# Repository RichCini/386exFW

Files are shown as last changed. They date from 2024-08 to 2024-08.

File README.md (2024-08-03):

# 386ex Firmware Prototyping/Design Board
386EX-target firmware design board based on the design from Ed Nisley and his Firmware Furnace column
in Circuit Cellar. The article series spanned Issues 31 to 65 (roughly 1993 to 1995). The hardware
design -- a short ISA card built on a Jameco prototyping card -- provided an easy way to interface
to the ISA bus and had memory (EEPROM/ROM/NVRAM). a timer, watchdog, LED and switch inputs, and two
types of LCD displays. 

The first part of the series (Issues 31- 46) dealt with the hardware design, while later articles
discussed something Ed called the "Firmware Furnace Task Switcher", a functional protected-mode
software platform. The software discussion began in Issue 48 and ended with Issue 65. Issue 65
seems to point to future columns on the topic, but they never seemed to appear.

## Status
The schematics have been converted and the board plotted. It has not been built yet. Of the
design elements, the only feature I didn't redraw was the bitmapped graphics LCD panel, the
discission of which began in Issue 42. Options were the Optrex (Kyocera) DMF651 640x200 or the 
Matsushita EDM-LG64AA44D 640x400 panel.

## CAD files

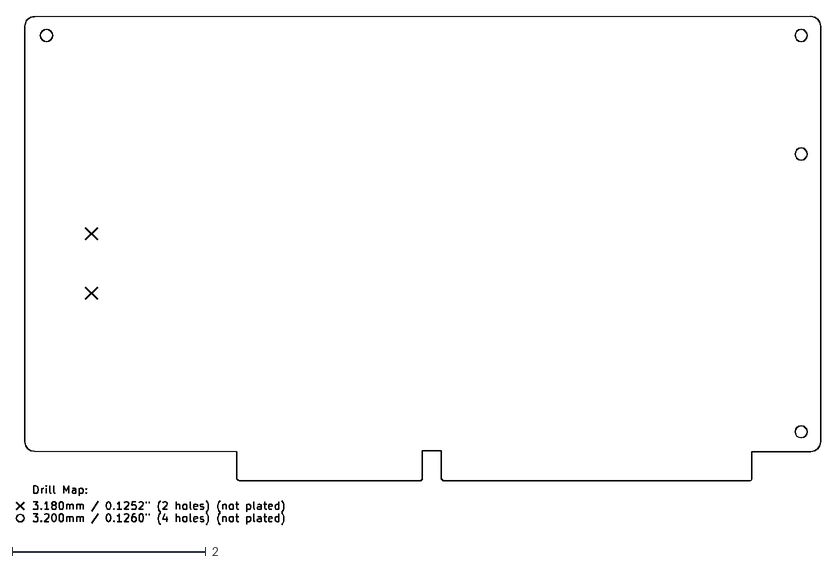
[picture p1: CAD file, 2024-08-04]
mfg/386sxEmbedded-NPTH-drl_map.dxf
8.30 x 5.24

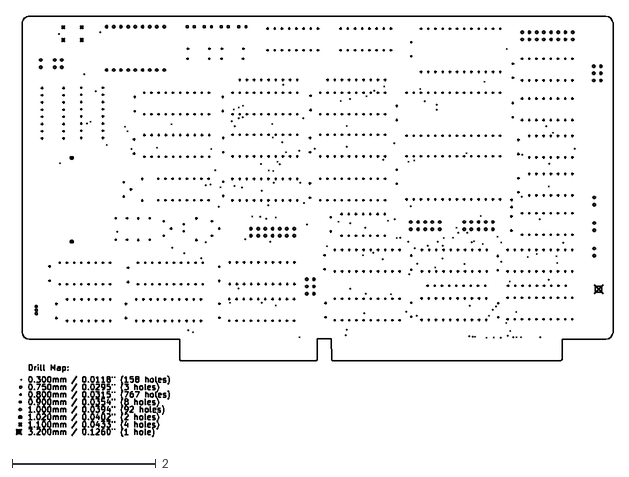
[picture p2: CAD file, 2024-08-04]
mfg/386sxEmbedded-PTH-drl_map.dxf
8.30 x 5.84

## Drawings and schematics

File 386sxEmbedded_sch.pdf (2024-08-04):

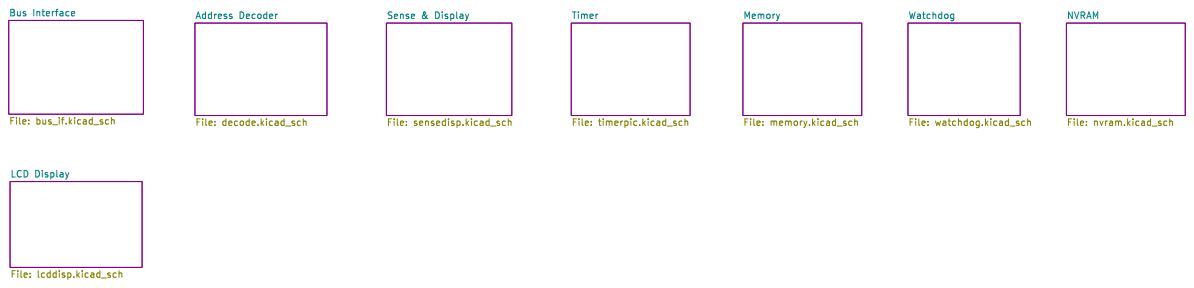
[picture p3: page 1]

Id: 1/9 Title: 386SX Embedded Expansion Card

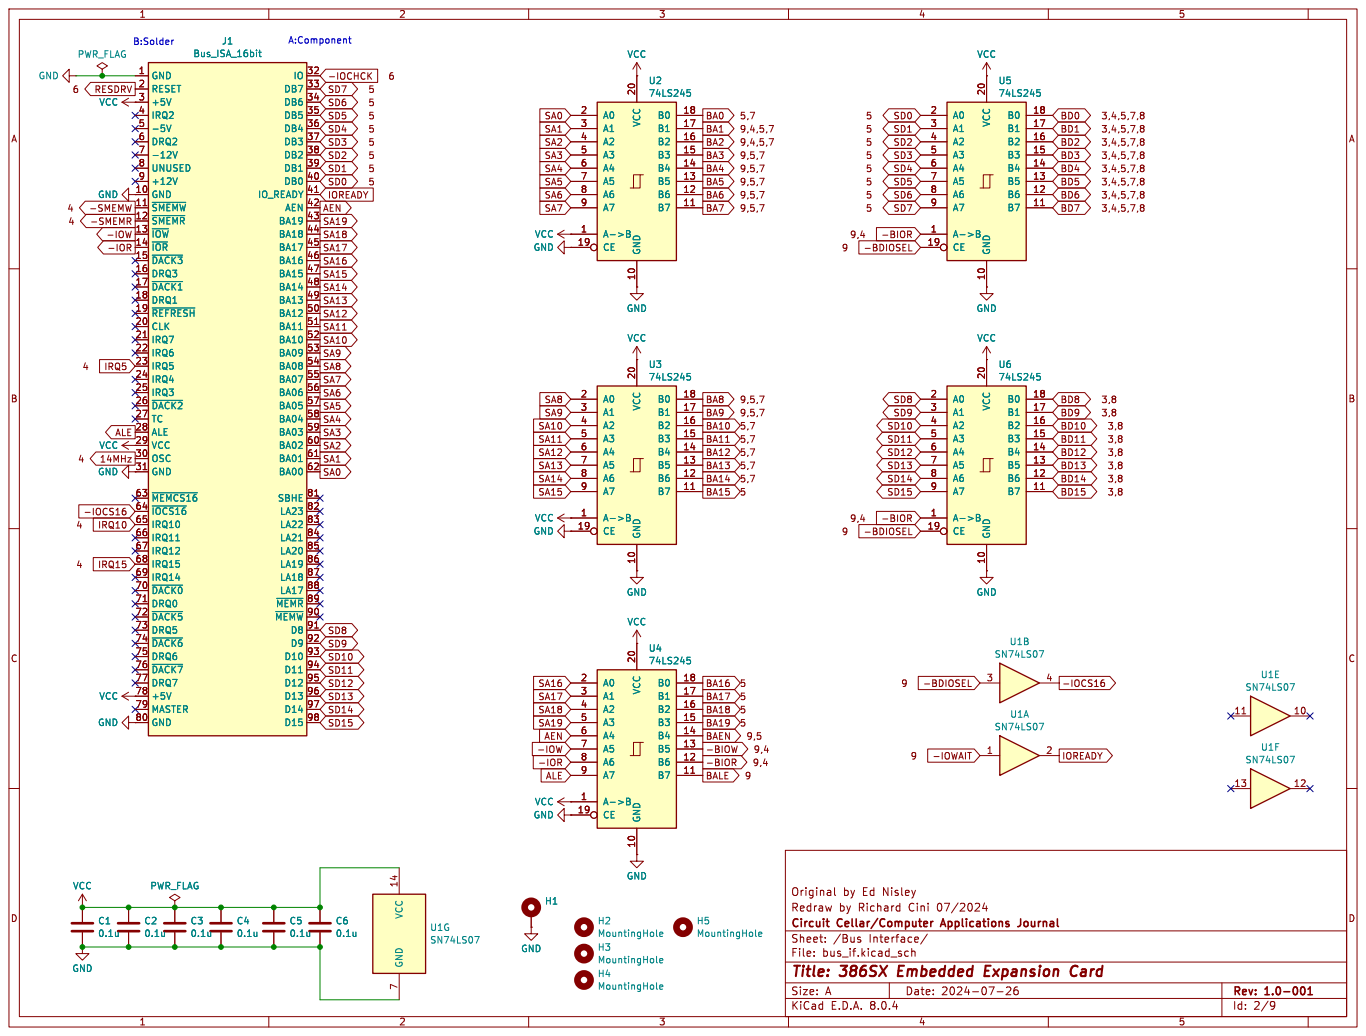
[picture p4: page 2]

Id: 2/9 Title: 386SX Embedded Expansion Card

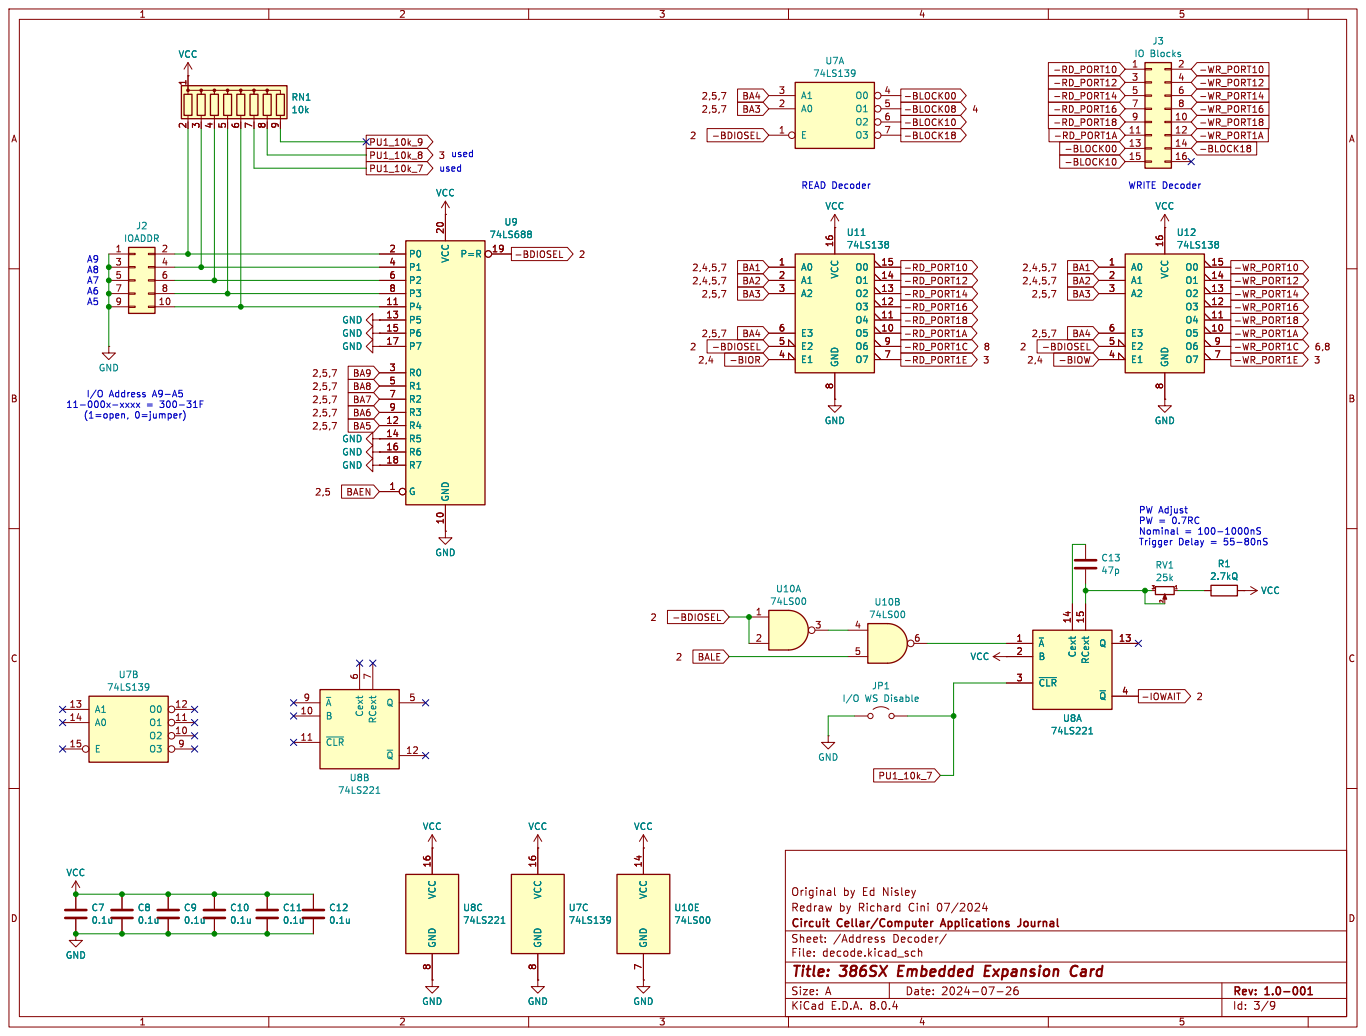
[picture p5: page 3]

8 O6 9 VCC GND GND GND GND GND GND GND

Id: 3/9 Title: 386SX Embedded Expansion Card

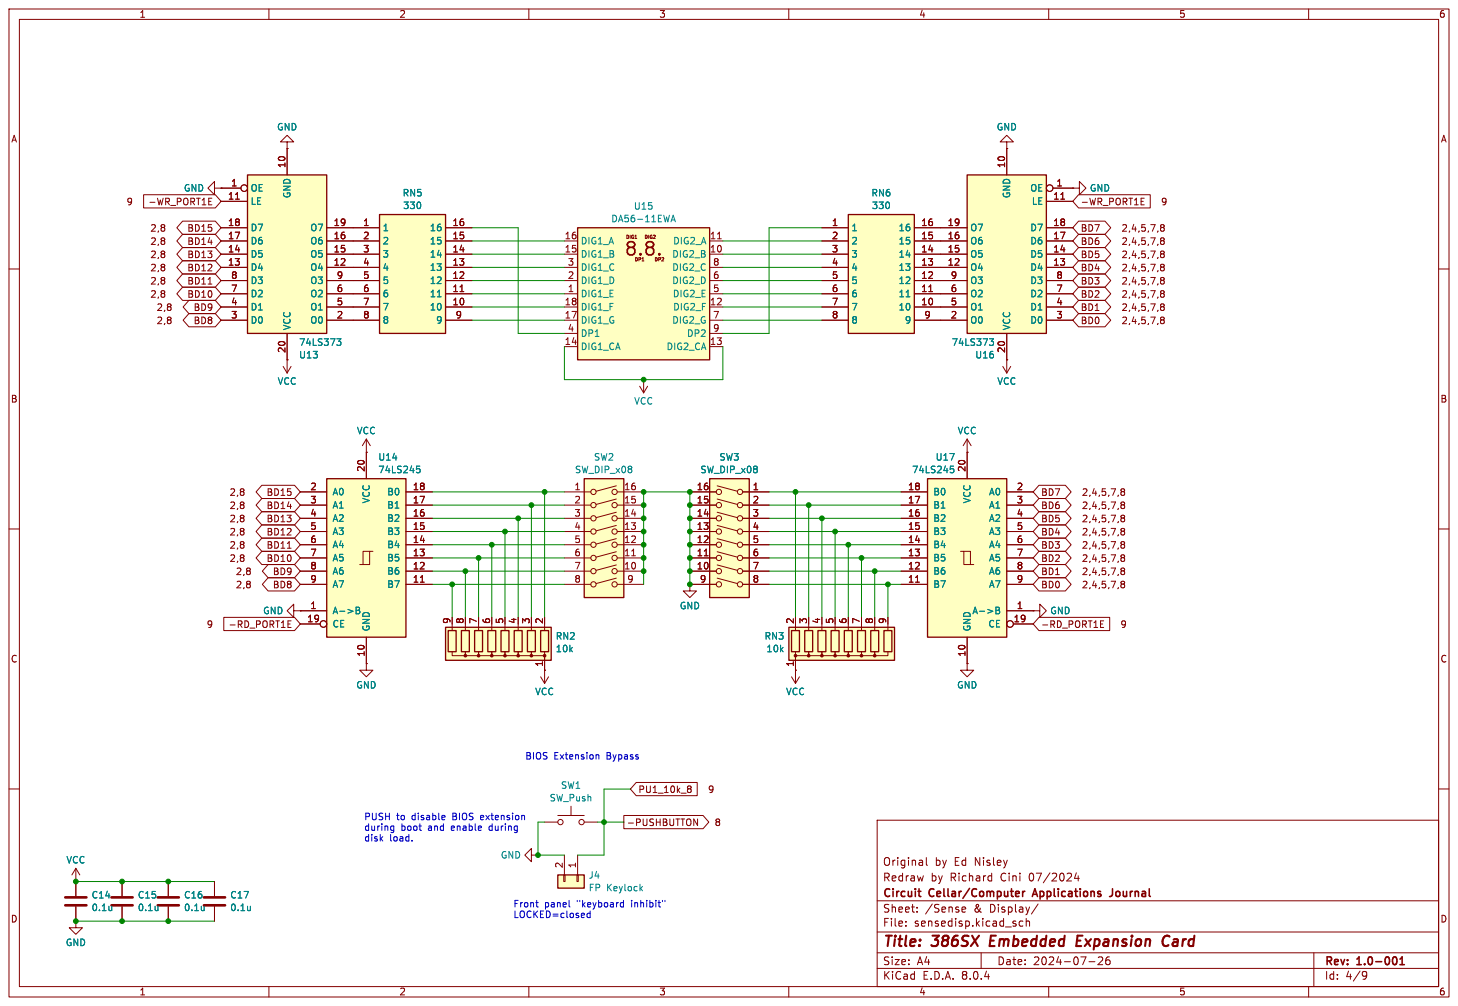
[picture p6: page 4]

during boot and enable during

Id: 4/9 Title: 386SX Embedded Expansion Card

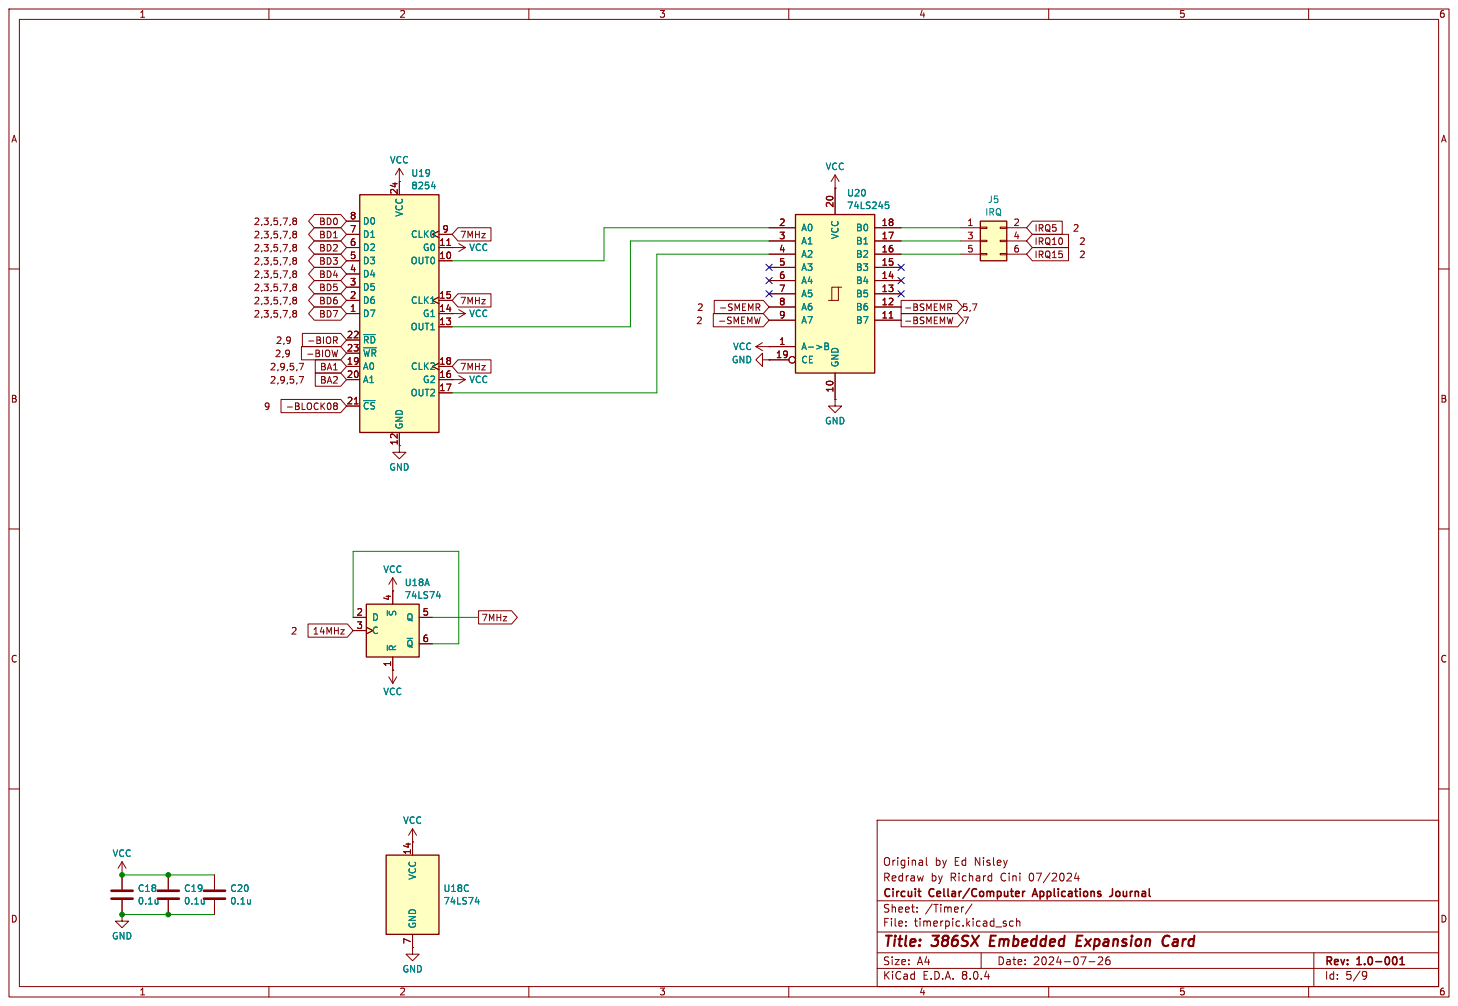
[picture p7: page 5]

Id: 5/9 Title: 386SX Embedded Expansion Card

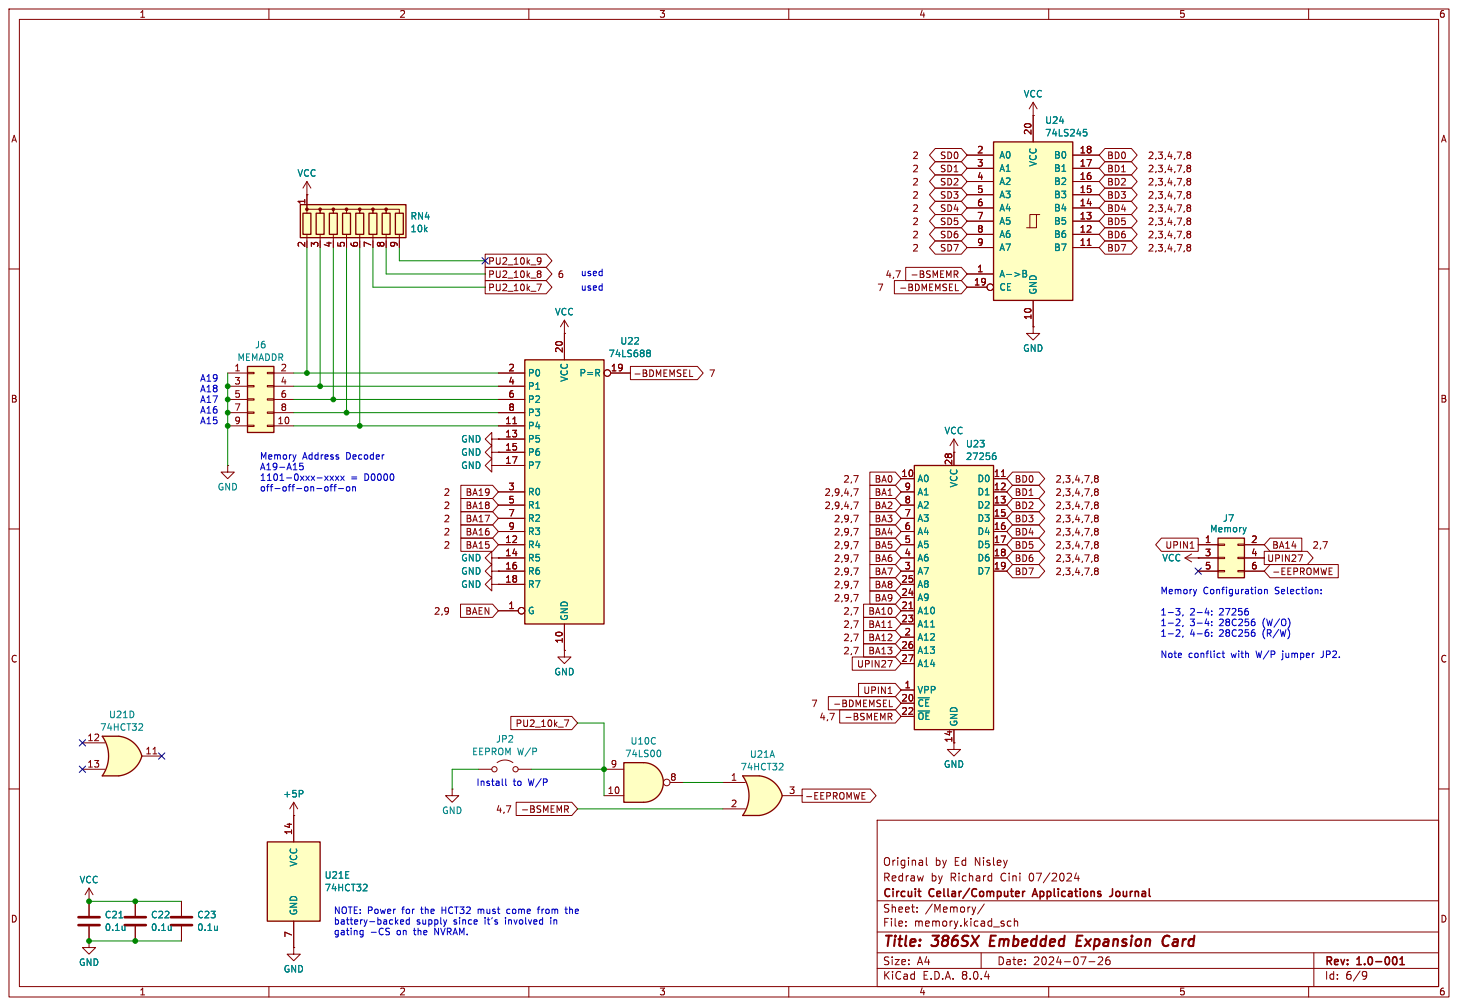
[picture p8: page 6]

9 VCC GND GND GND GND GND GND

off-off-on-off-on

gating -CS on the NVRAM.

Id: 6/9 Title: 386SX Embedded Expansion Card

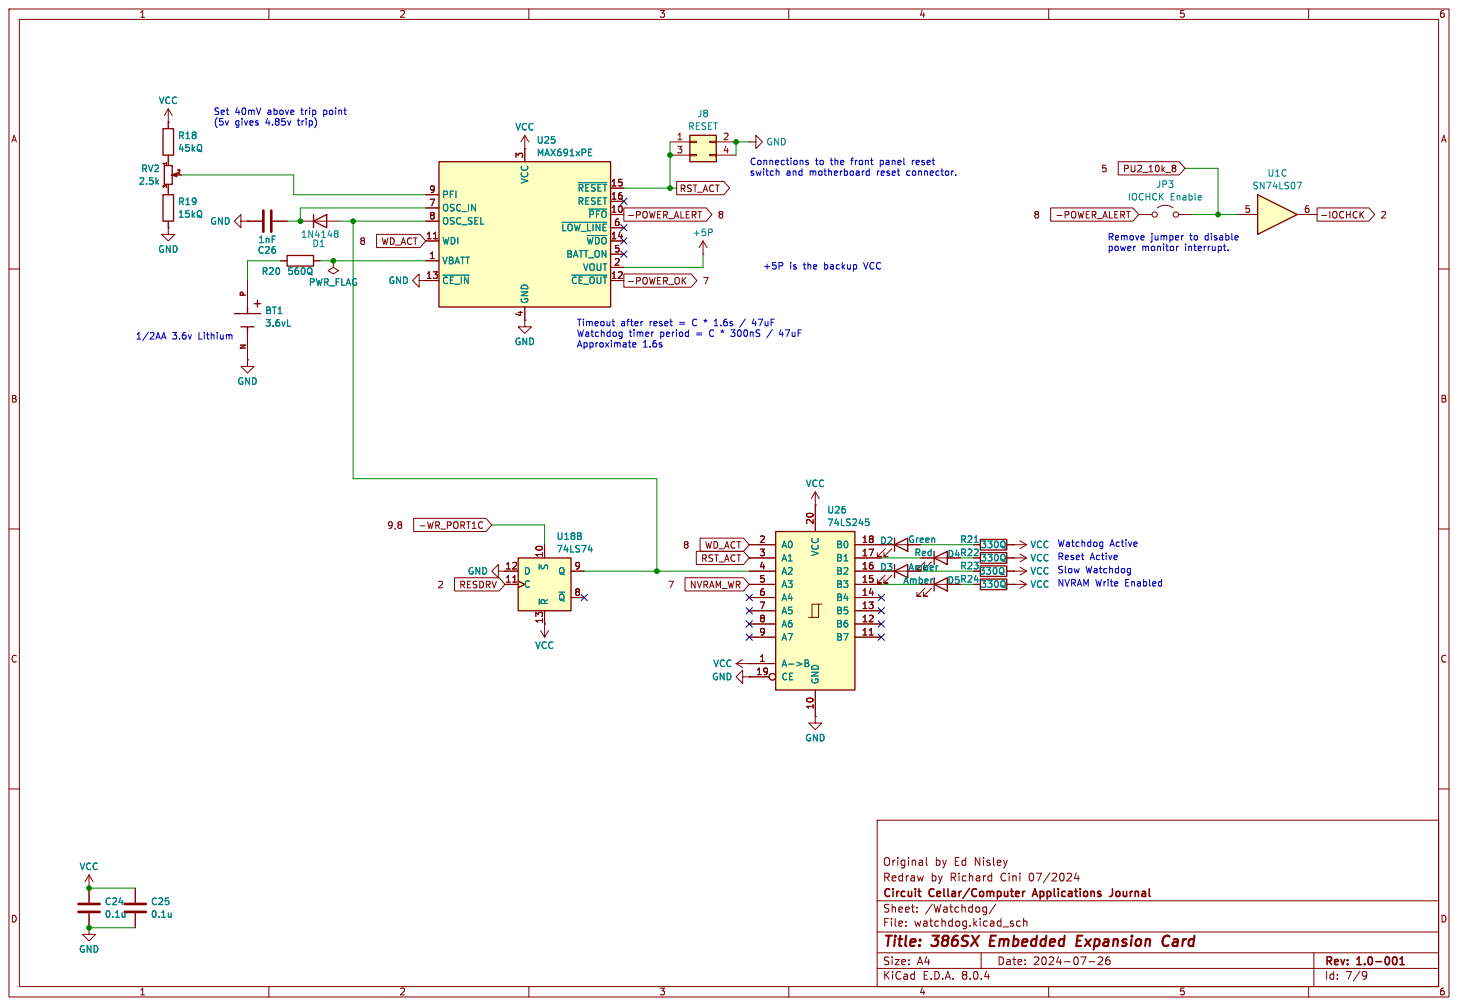
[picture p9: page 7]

Set 40mV above trip point

Id: 7/9 Title: 386SX Embedded Expansion Card

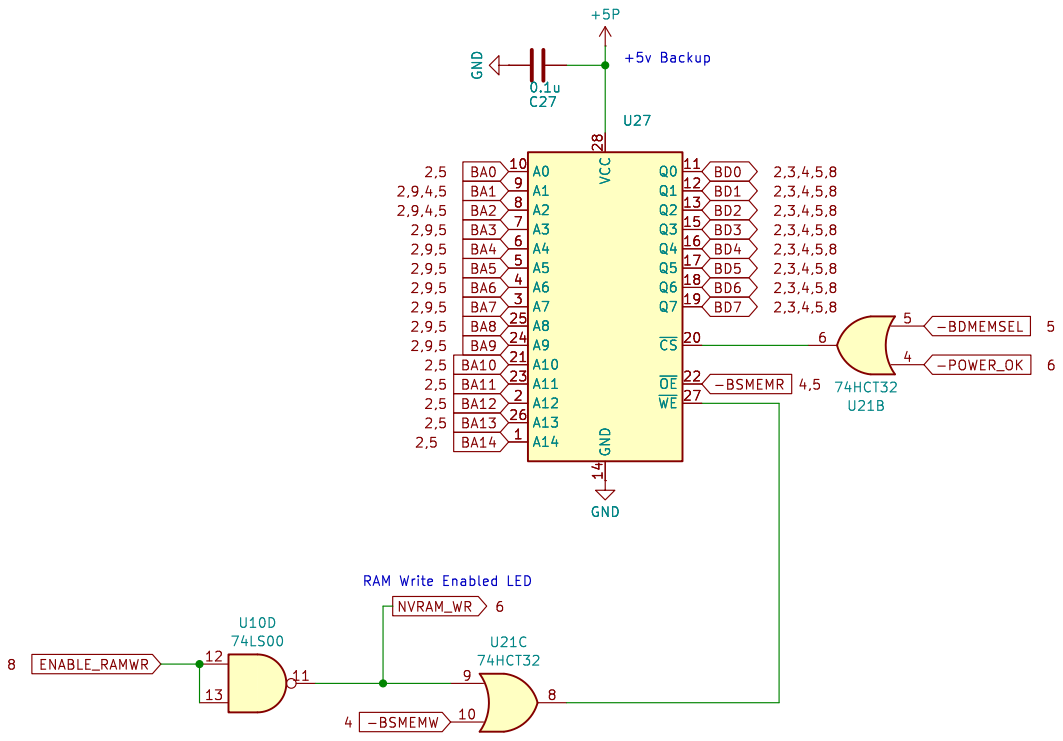
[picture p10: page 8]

Id: 8/9 Title: 386SX Embedded Expansion Card

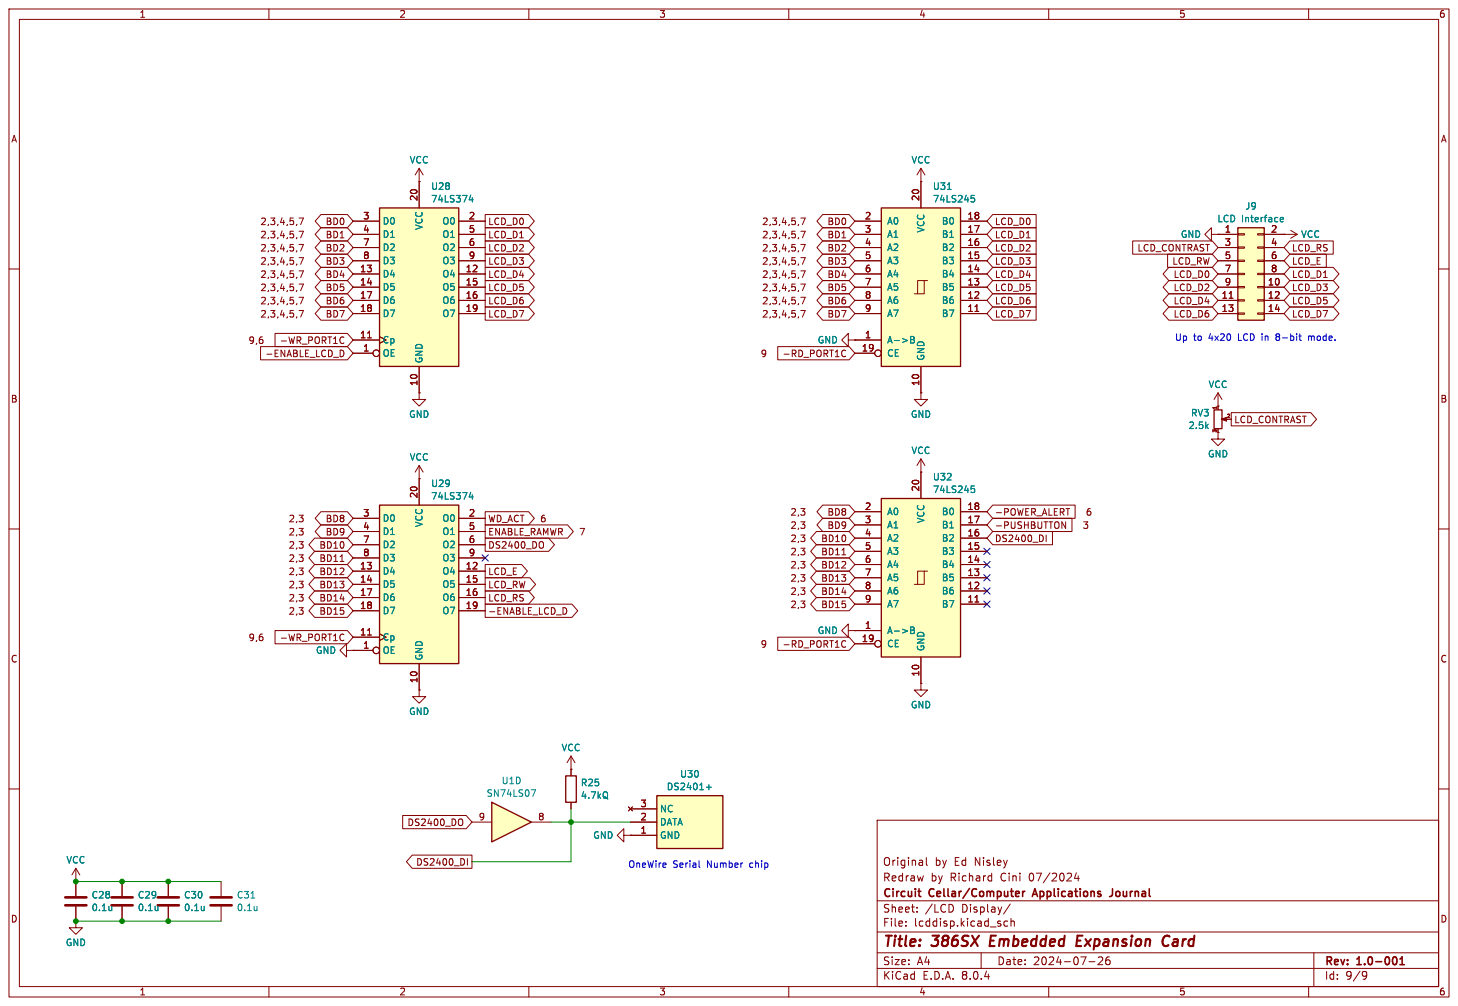
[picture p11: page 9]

Id: 9/9 Title: 386SX Embedded Expansion Card

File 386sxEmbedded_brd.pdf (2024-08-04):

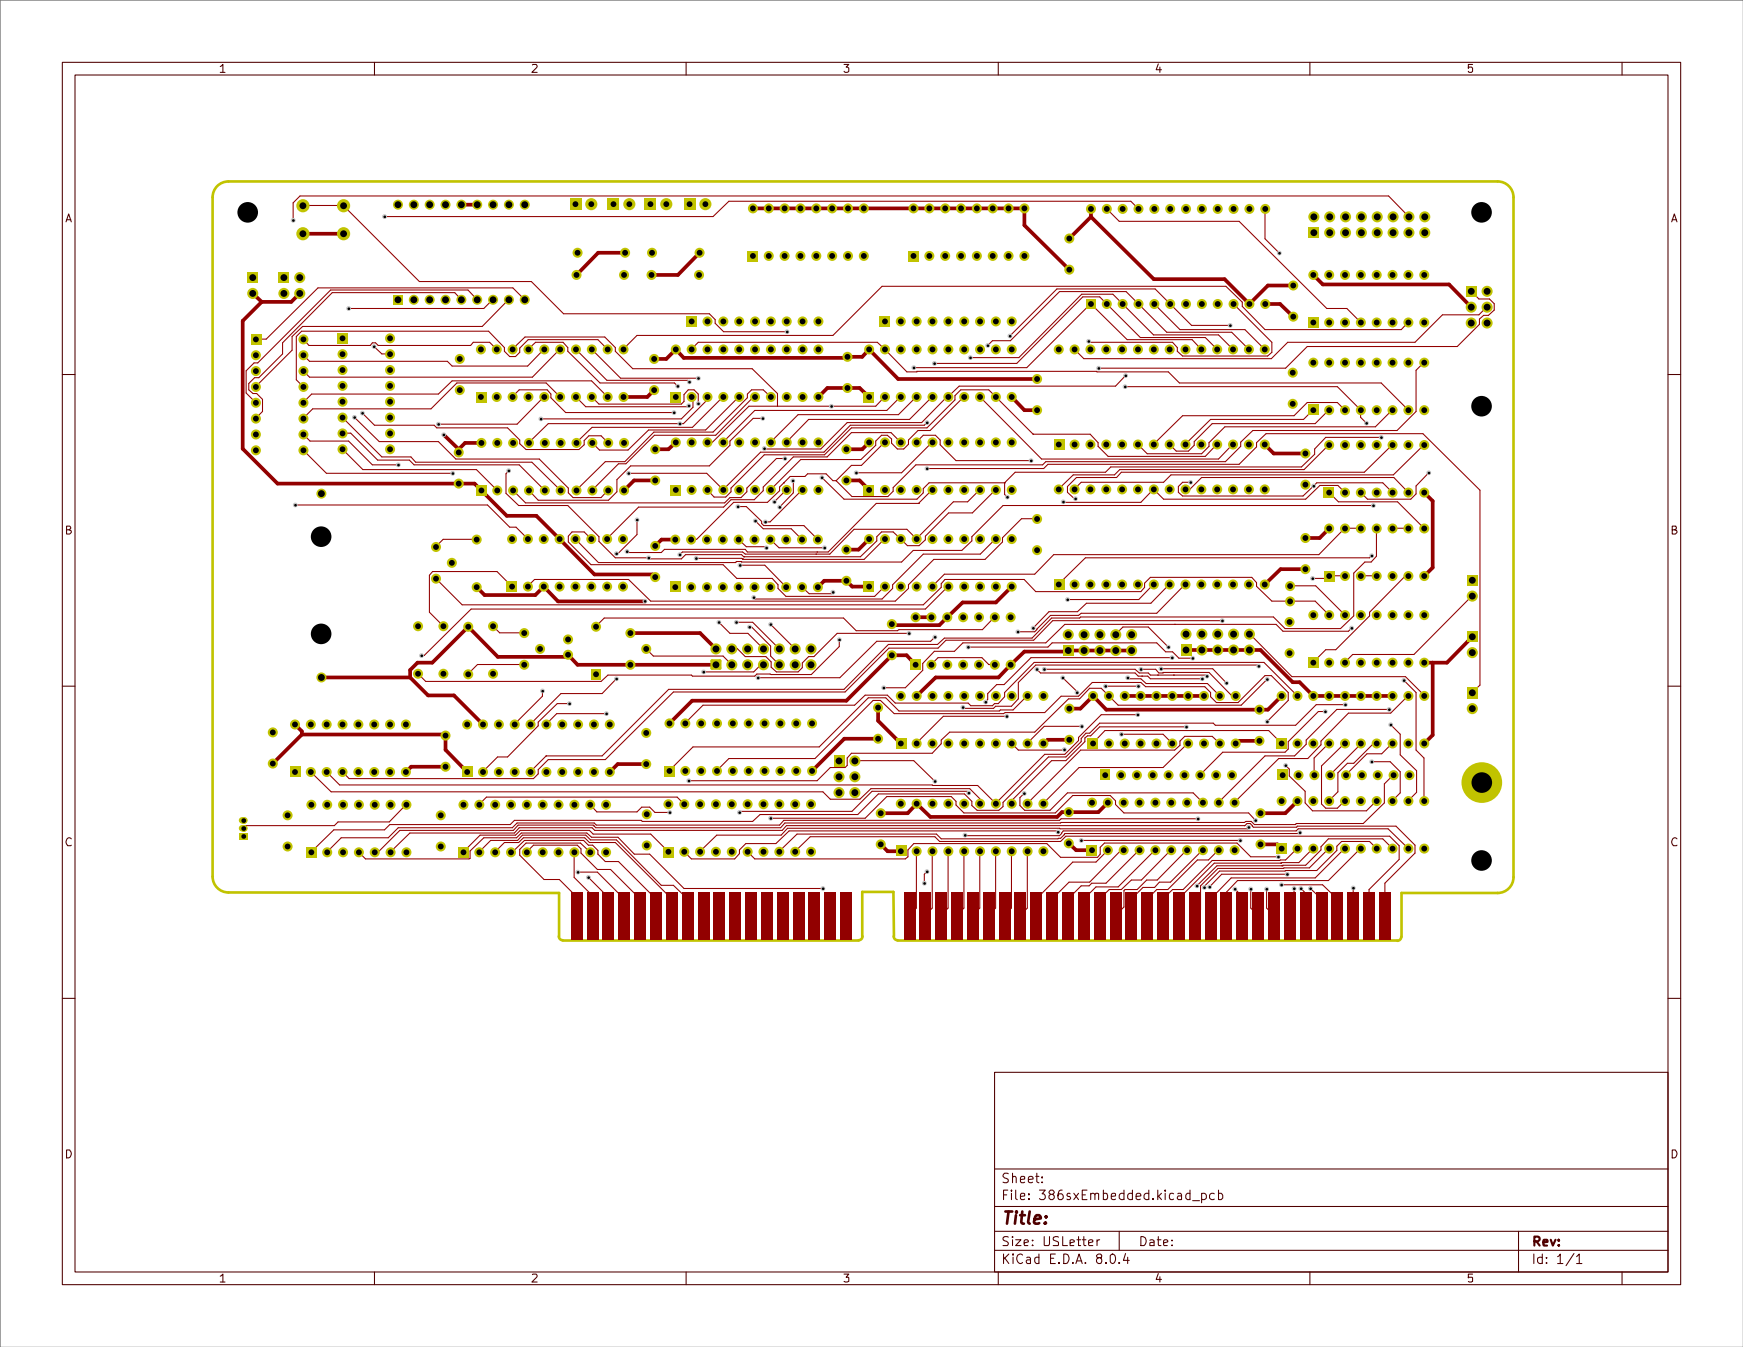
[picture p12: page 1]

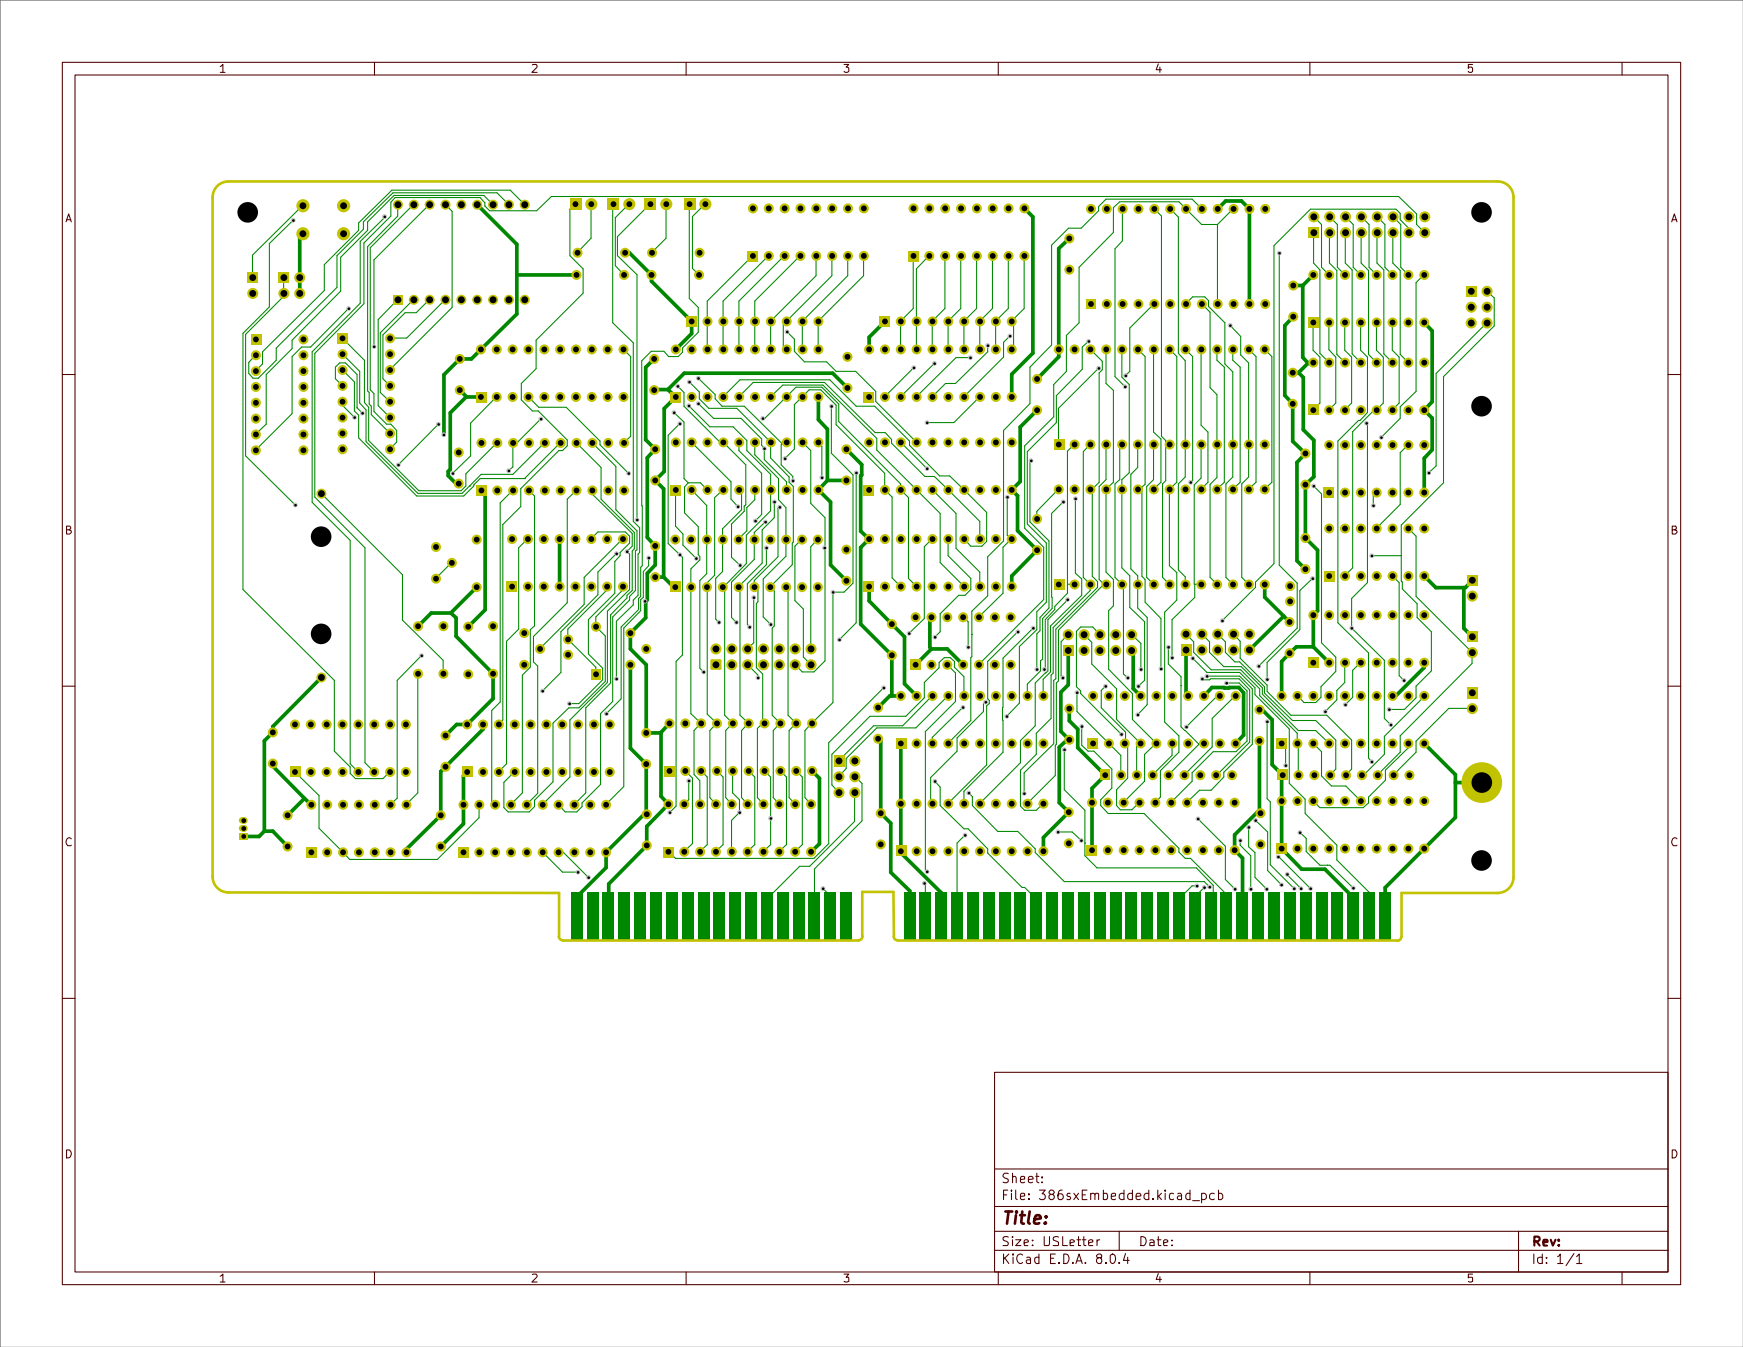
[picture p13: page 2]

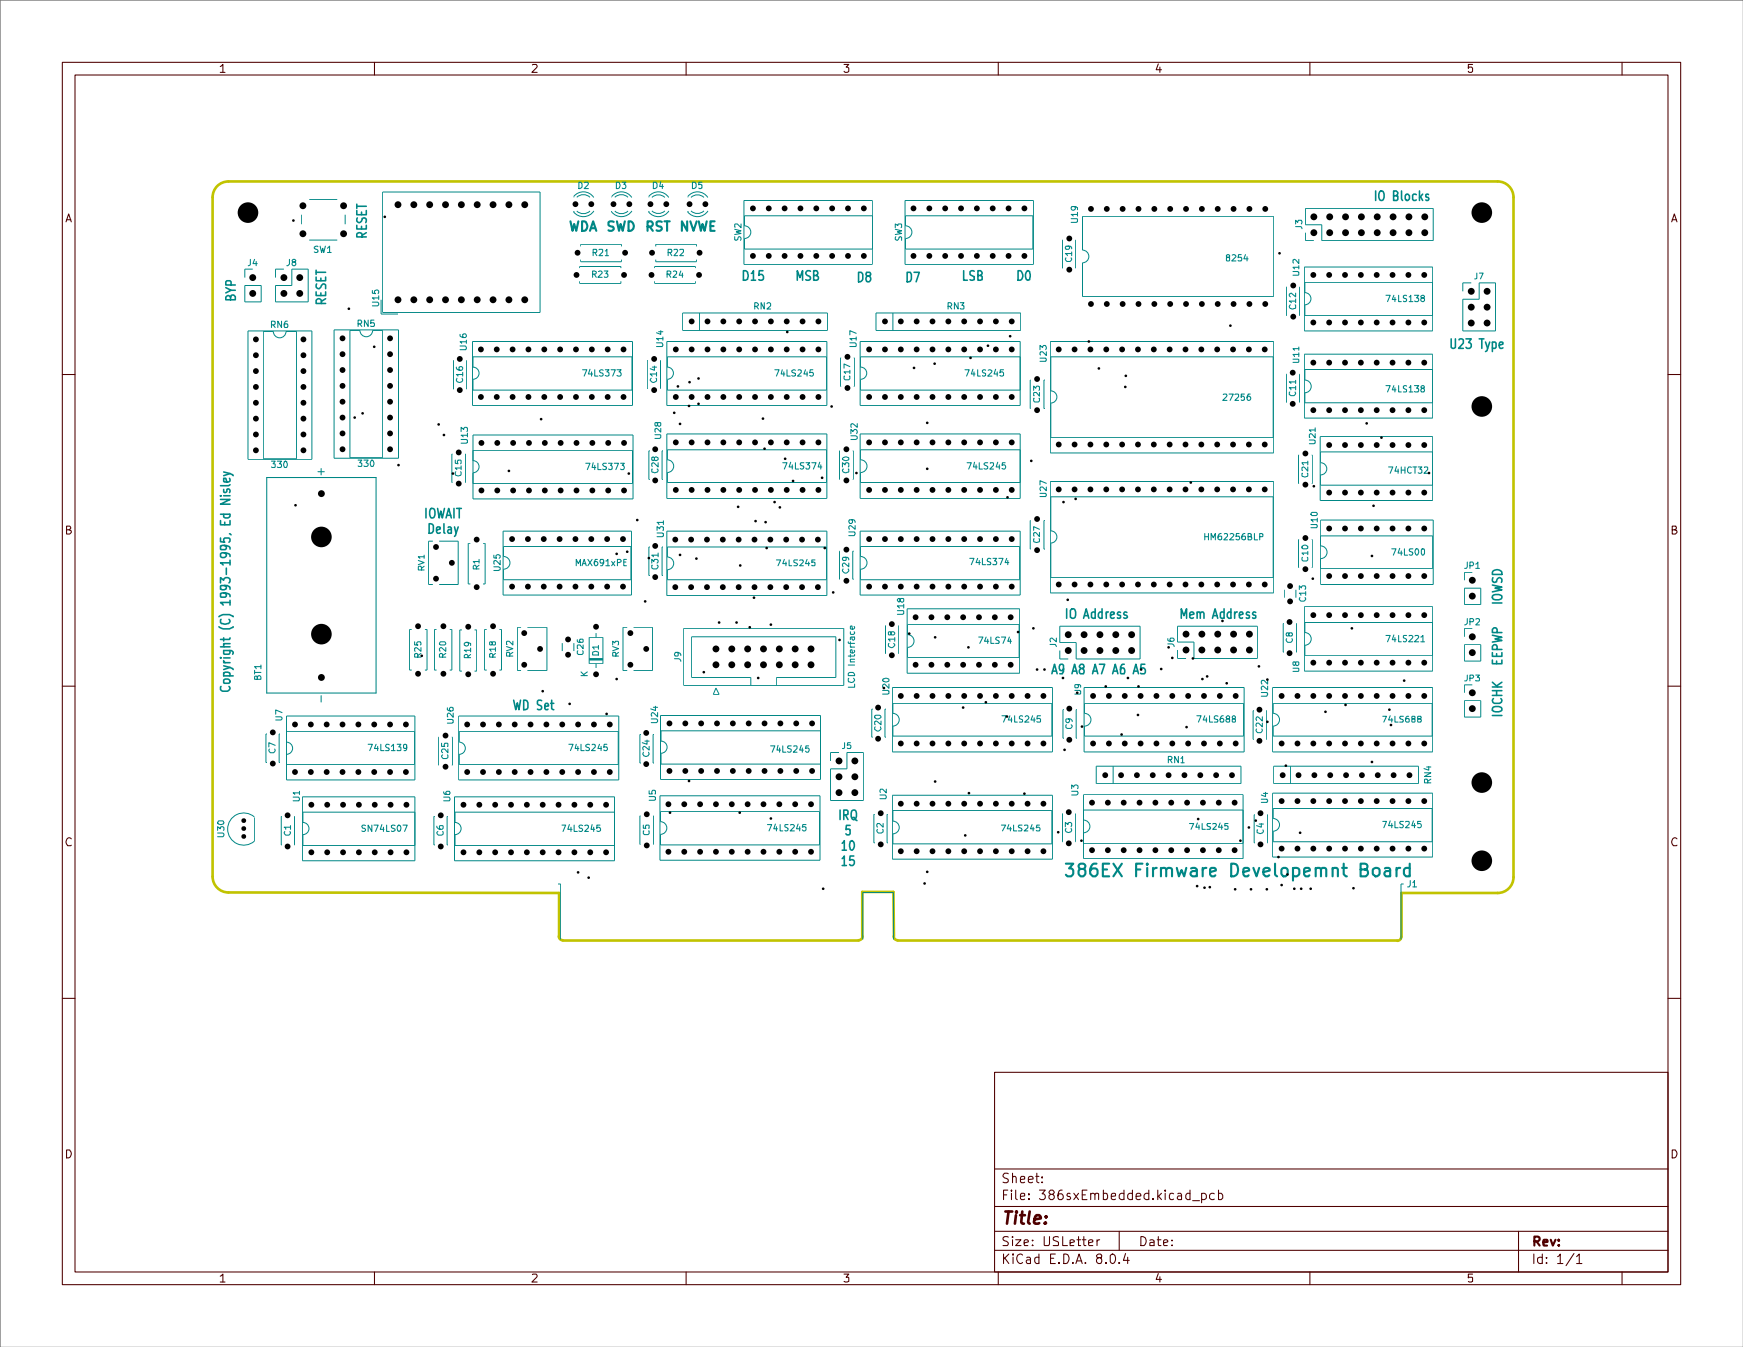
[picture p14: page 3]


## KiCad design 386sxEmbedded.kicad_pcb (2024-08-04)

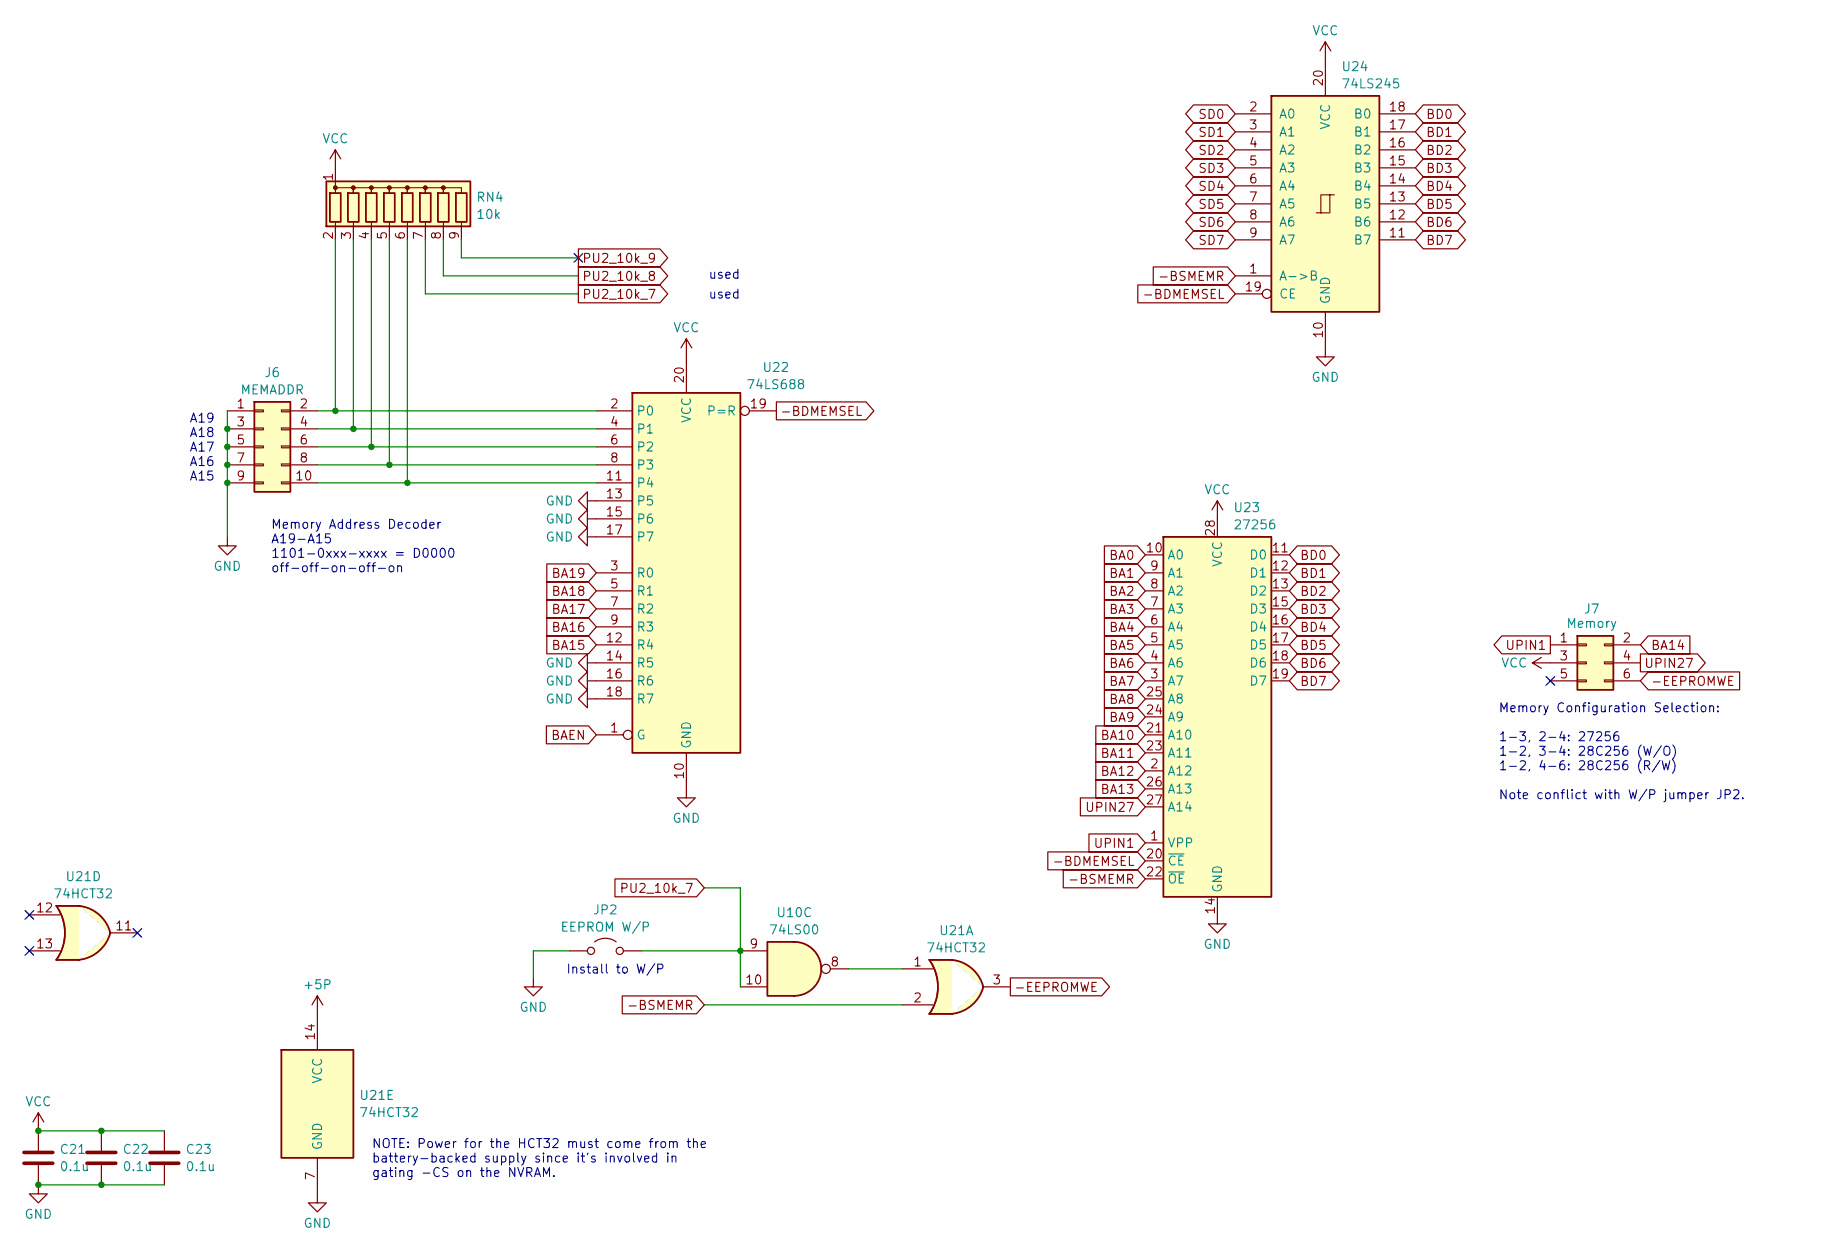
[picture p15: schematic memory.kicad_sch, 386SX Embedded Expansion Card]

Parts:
C21, C22, C23: 0.1u; C_Disc_D4.3mm_W1.9mm_P5.00mm
J6: MEMADDR; PinHeader_2x05_P2.54mm_Vertical
J7: Memory; PinHeader_2x03_P2.54mm_Vertical
JP2: EEPROM W/P; PinHeader_1x02_P2.54mm_Vertical
RN4: 10k; R_Array_SIP9
U10: 74LS00; DIP-14_W7.62mm_Socket
U21: 74HCT32; DIP-14_W7.62mm_Socket
U22: 74LS688; DIP-20_W7.62mm_Socket
U23: 27256; DIP-28_W15.24mm_Socket
U24: 74LS245; DIP-20_W7.62mm_Socket

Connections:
+5P: U21.14 (VCC); also elsewhere on the board
-BDMEMSEL: U22.19 (P=R), U23.20 (~CE), U24.19 (CE); also elsewhere on the board
-BSMEMR: U21.2, U23.22 (~OE), U24.1 (A->B); also elsewhere on the board
-EEPROMWE: J7.6, U21.3
BA0: U23.10 (A0); also elsewhere on the board
BA1: U23.9 (A1); also elsewhere on the board
BA2: U23.8 (A2); also elsewhere on the board
BA3: U23.7 (A3); also elsewhere on the board
BA4: U23.6 (A4); also elsewhere on the board
BA5: U23.5 (A5); also elsewhere on the board
BA6: U23.4 (A6); also elsewhere on the board
BA7: U23.3 (A7); also elsewhere on the board
BA8: U23.25 (A8); also elsewhere on the board
BA9: U23.24 (A9); also elsewhere on the board
BA10: U23.21 (A10); also elsewhere on the board
BA11: U23.23 (A11); also elsewhere on the board
BA12: U23.2 (A12); also elsewhere on the board
BA13: U23.26 (A13); also elsewhere on the board
BA14: J7.2; also elsewhere on the board
BA15: U22.12 (R4); also elsewhere on the board
BA16: U22.9 (R3); also elsewhere on the board
BA17: U22.7 (R2); also elsewhere on the board
BA18: U22.5 (R1); also elsewhere on the board
BA19: U22.3 (R0); also elsewhere on the board
BAEN: U22.1 (G); also elsewhere on the board
BD0: U23.11 (D0), U24.18 (B0); also elsewhere on the board
BD1: U23.12 (D1), U24.17 (B1); also elsewhere on the board
BD2: U23.13 (D2), U24.16 (B2); also elsewhere on the board
BD3: U23.15 (D3), U24.15 (B3); also elsewhere on the board
BD4: U23.16 (D4), U24.14 (B4); also elsewhere on the board
BD5: U23.17 (D5), U24.13 (B5); also elsewhere on the board
BD6: U23.18 (D6), U24.12 (B6); also elsewhere on the board
BD7: U23.19 (D7), U24.11 (B7); also elsewhere on the board
GND: C21.2, C22.2, C23.2, J6.1, J6.3, J6.5, J6.7, J6.9, JP2.1 (A), U21.7 (GND), U22.10 (GND), U22.13 (P5), U22.14 (R5), U22.15 (P6), U22.16 (R6), U22.17 (P7), U22.18 (R7), U23.14 (GND), U24.10 (GND); also elsewhere on the board
unnamed: J6.2, RN4.2 (R1), U22.2 (P0)
unnamed: J6.4, RN4.3 (R2), U22.4 (P1)
unnamed: J6.6, RN4.4 (R3), U22.6 (P2)
unnamed: J6.8, RN4.5 (R4), U22.8 (P3)
unnamed: J6.10, RN4.6 (R5), U22.11 (P4)
unnamed: U10.8, U21.1
PU2_10k_7: JP2.2 (B), RN4.7 (R6), U10.9, U10.10
PU2_10k_8: RN4.8 (R7); also elsewhere on the board
PU2_10k_9: RN4.9 (R8)
SD0: U24.2 (A0); also elsewhere on the board
SD1: U24.3 (A1); also elsewhere on the board
SD2: U24.4 (A2); also elsewhere on the board
SD3: U24.5 (A3); also elsewhere on the board
SD4: U24.6 (A4); also elsewhere on the board
SD5: U24.7 (A5); also elsewhere on the board
SD6: U24.8 (A6); also elsewhere on the board
SD7: U24.9 (A7); also elsewhere on the board
UPIN1: J7.1, U23.1 (VPP)
UPIN27: J7.4, U23.27 (A14)
VCC: C21.1, C22.1, C23.1, J7.3, RN4.1 (common), U22.20 (VCC), U23.28 (VCC), U24.20 (VCC); also elsewhere on the board

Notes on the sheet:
used
NOTE: Power for the HCT32 must come from the battery-backed supply since it's involved in gating -CS on the NVRAM.
Memory Address Decoder A19-A15 1101-0xxx-xxxx = D0000 off-off-on-off-on
Memory Configuration Selection: 1-3, 2-4: 27256 1-2, 3-4: 28C256 (W/O) 1-2, 4-6: 28C256 (R/W) Note conflict with W/P jumper JP2.
Install to W/P
A19 A18 A17 A16 A15

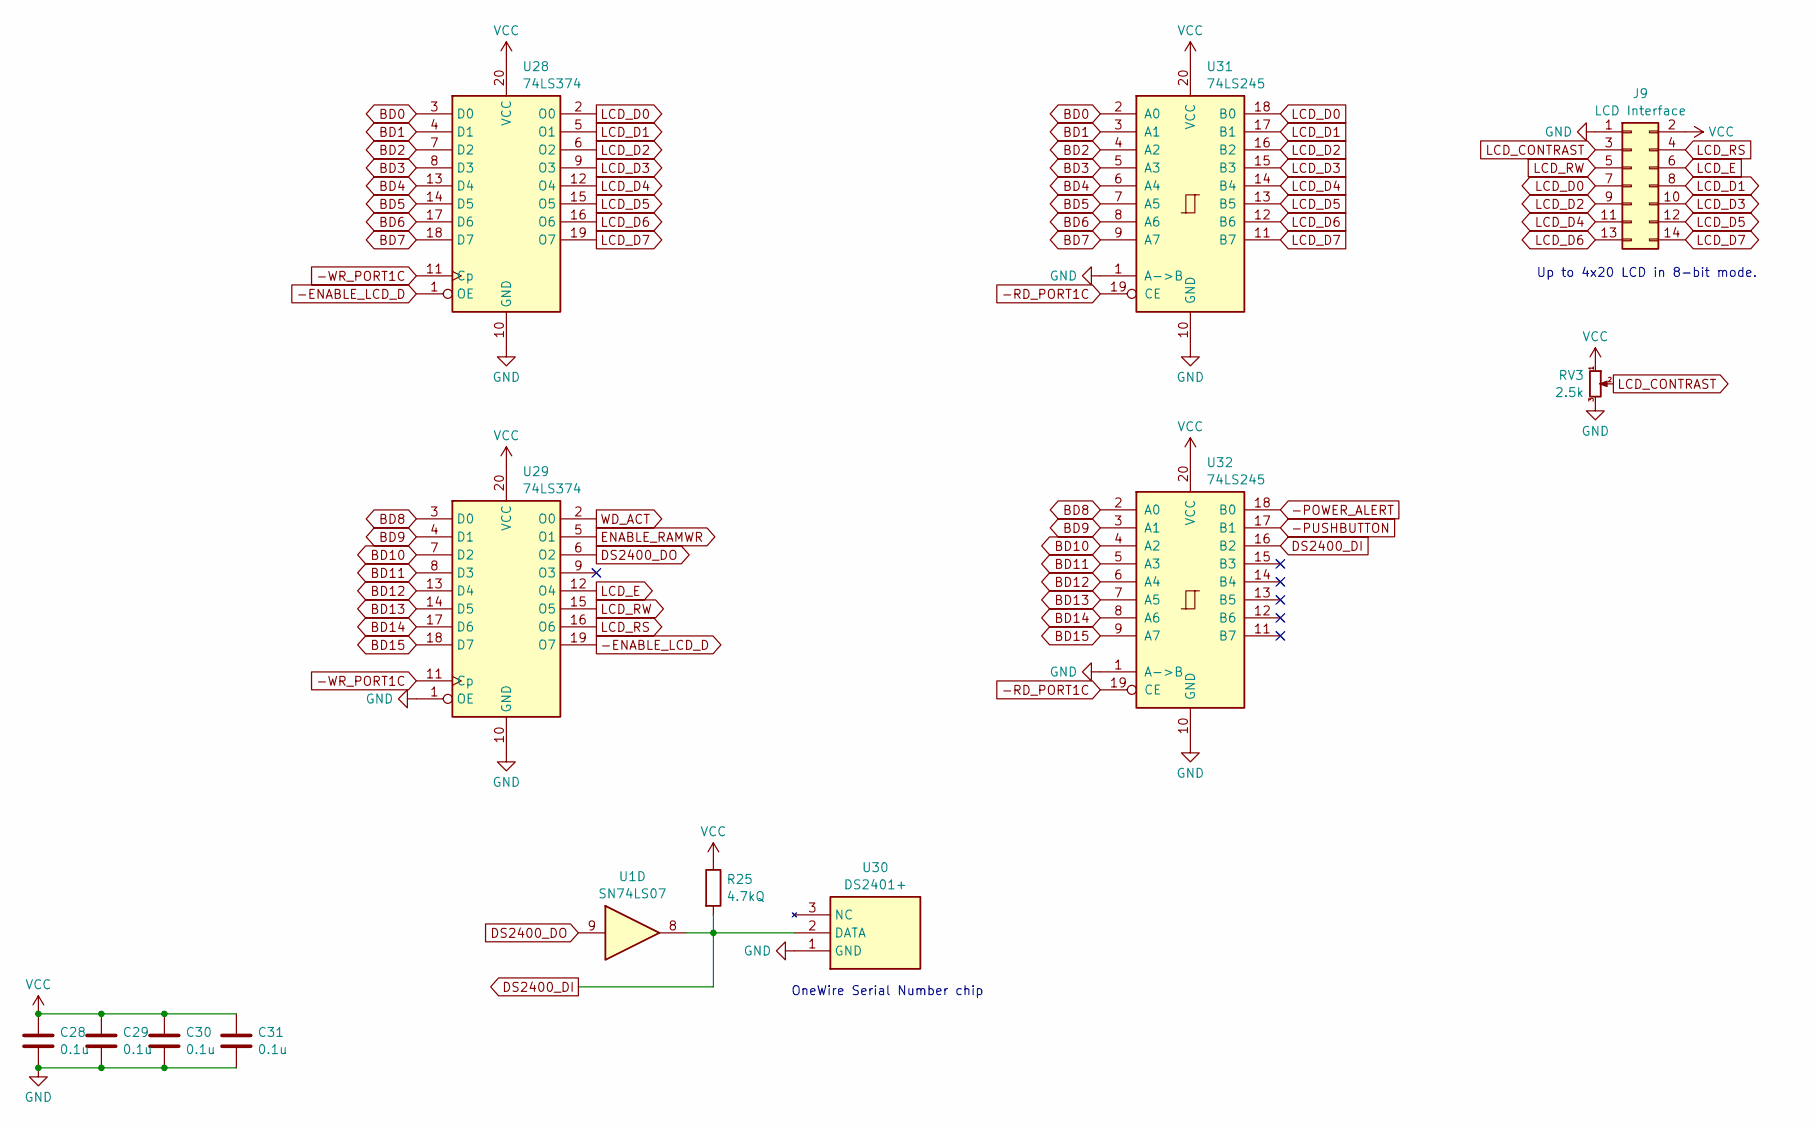
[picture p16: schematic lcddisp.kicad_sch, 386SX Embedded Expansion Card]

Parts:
C28, C29, C30, C31: 0.1u; C_Disc_D4.3mm_W1.9mm_P5.00mm
J9: LCD Interface; IDC-Header_2x07_P2.54mm_Vertical
R25: 4.7kQ; R_Axial_DIN0207_L6.3mm_D2.5mm_P7.62mm_Horizontal
RV3: 2.5k; Potentiometer_Bourns_3266W_Vertical
U1: SN74LS07; DIP-14_W7.62mm_Socket
U28, U29: 74LS374; DIP-20_W7.62mm_Socket
U30: DS2401+; TO-92L_Inline; Mouser Part Number 700-DS2401
U31, U32: 74LS245; DIP-20_W7.62mm_Socket

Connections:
-ENABLE_LCD_D: U28.1 (OE), U29.19 (O7)
-POWER_ALERT: U32.18 (B0); also elsewhere on the board
-PUSHBUTTON: U32.17 (B1); also elsewhere on the board
-RD_PORT1C: U31.19 (CE), U32.19 (CE); also elsewhere on the board
-WR_PORT1C: U28.11 (Cp), U29.11 (Cp); also elsewhere on the board
BD0: U28.3 (D0), U31.2 (A0); also elsewhere on the board
BD1: U28.4 (D1), U31.3 (A1); also elsewhere on the board
BD2: U28.7 (D2), U31.4 (A2); also elsewhere on the board
BD3: U28.8 (D3), U31.5 (A3); also elsewhere on the board
BD4: U28.13 (D4), U31.6 (A4); also elsewhere on the board
BD5: U28.14 (D5), U31.7 (A5); also elsewhere on the board
BD6: U28.17 (D6), U31.8 (A6); also elsewhere on the board
BD7: U28.18 (D7), U31.9 (A7); also elsewhere on the board
BD8: U29.3 (D0), U32.2 (A0); also elsewhere on the board
BD9: U29.4 (D1), U32.3 (A1); also elsewhere on the board
BD10: U29.7 (D2), U32.4 (A2); also elsewhere on the board
BD11: U29.8 (D3), U32.5 (A3); also elsewhere on the board
BD12: U29.13 (D4), U32.6 (A4); also elsewhere on the board
BD13: U29.14 (D5), U32.7 (A5); also elsewhere on the board
BD14: U29.17 (D6), U32.8 (A6); also elsewhere on the board
BD15: U29.18 (D7), U32.9 (A7); also elsewhere on the board
DS2400_DI: R25.2, U1.8, U30.2 (DATA), U32.16 (B2)
DS2400_DO: U1.9, U29.6 (O2)
ENABLE_RAMWR: U29.5 (O1); also elsewhere on the board
GND: C28.2, C29.2, C30.2, C31.2, J9.1, RV3.3, U28.10 (GND), U29.1 (OE), U29.10 (GND), U30.1 (GND), U31.1 (A->B), U31.10 (GND), U32.1 (A->B), U32.10 (GND); also elsewhere on the board
LCD_CONTRAST: J9.3, RV3.2
LCD_D0: J9.7, U28.2 (O0), U31.18 (B0)
LCD_D1: J9.8, U28.5 (O1), U31.17 (B1)
LCD_D2: J9.9, U28.6 (O2), U31.16 (B2)
LCD_D3: J9.10, U28.9 (O3), U31.15 (B3)
LCD_D4: J9.11, U28.12 (O4), U31.14 (B4)
LCD_D5: J9.12, U28.15 (O5), U31.13 (B5)
LCD_D6: J9.13, U28.16 (O6), U31.12 (B6)
LCD_D7: J9.14, U28.19 (O7), U31.11 (B7)
LCD_E: J9.6, U29.12 (O4)
LCD_RS: J9.4, U29.16 (O6)
LCD_RW: J9.5, U29.15 (O5)
VCC: C28.1, C29.1, C30.1, C31.1, J9.2, R25.1, RV3.1, U28.20 (VCC), U29.20 (VCC), U31.20 (VCC), U32.20 (VCC); also elsewhere on the board
WD_ACT: U29.2 (O0); also elsewhere on the board

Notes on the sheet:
OneWire Serial Number chip
Up to 4x20 LCD in 8-bit mode.

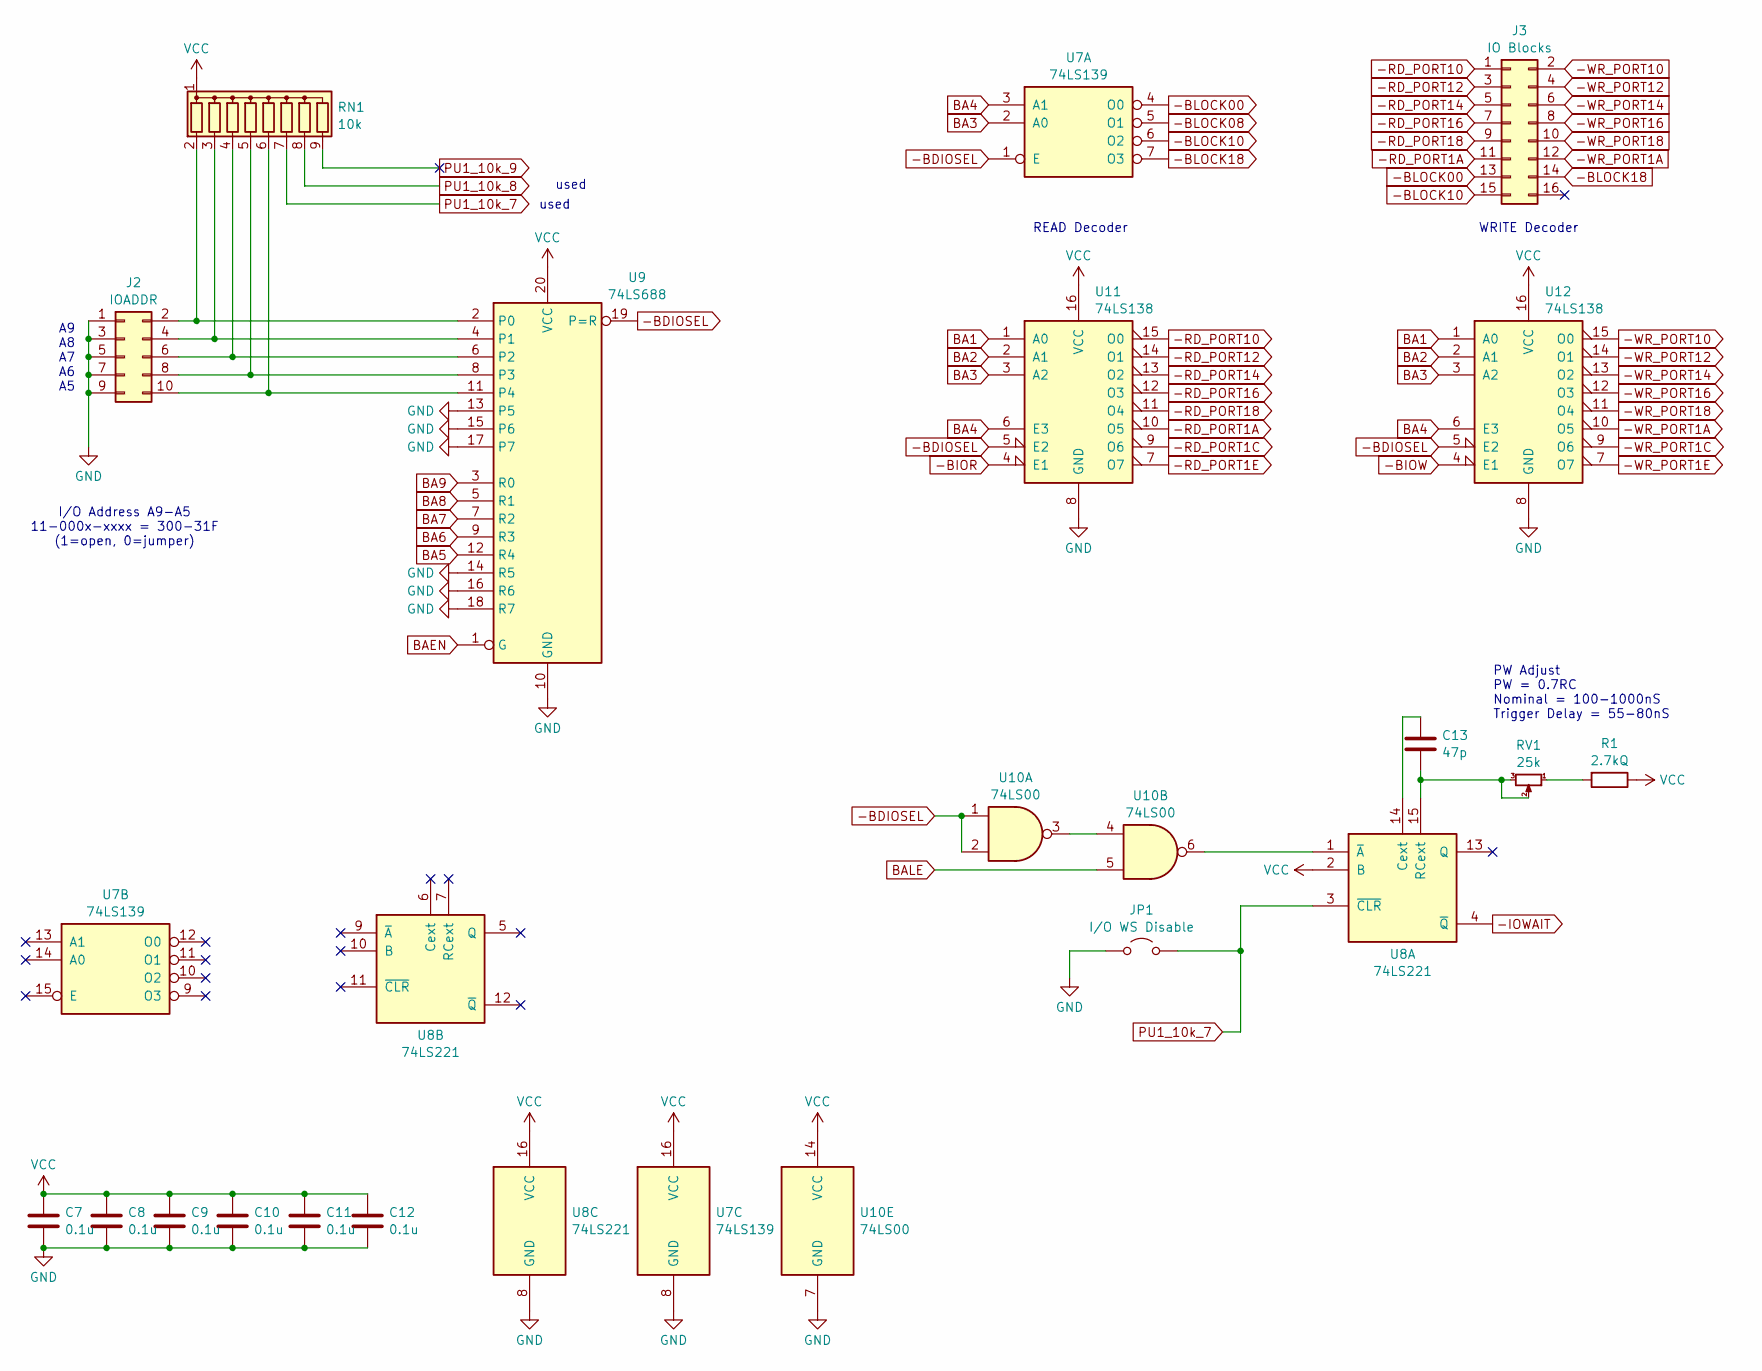
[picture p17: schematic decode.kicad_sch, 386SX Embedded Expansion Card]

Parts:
C7, C8, C9, C10, C11, C12: 0.1u; C_Disc_D4.3mm_W1.9mm_P5.00mm
C13: 47p; C_Disc_D3.0mm_W1.6mm_P2.50mm
J2: IOADDR; PinHeader_2x05_P2.54mm_Vertical
J3: IO Blocks; PinHeader_2x08_P2.54mm_Vertical
JP1: I/O WS Disable; PinHeader_1x02_P2.54mm_Vertical
R1: 2.7kQ; R_Axial_DIN0207_L6.3mm_D2.5mm_P7.62mm_Horizontal
RN1: 10k; R_Array_SIP9
RV1: 25k; Potentiometer_Bourns_3266W_Vertical
U7: 74LS139; DIP-16_W7.62mm_Socket
U8: 74LS221; DIP-16_W7.62mm_Socket
U9: 74LS688; DIP-20_W7.62mm_Socket
U10: 74LS00; DIP-14_W7.62mm_Socket
U11, U12: 74LS138; DIP-16_W7.62mm_Socket

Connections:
-BDIOSEL: U7.1 (E), U9.19 (P=R), U10.1, U10.2, U11.5 (E2), U12.5 (E2); also elsewhere on the board
-BIOR: U11.4 (E1); also elsewhere on the board
-BIOW: U12.4 (E1); also elsewhere on the board
-BLOCK00: J3.13, U7.4 (O0)
-BLOCK08: U7.5 (O1); also elsewhere on the board
-BLOCK10: J3.15, U7.6 (O2)
-BLOCK18: J3.14, U7.7 (O3)
-IOWAIT: U8.4 (~Q); also elsewhere on the board
-PUSHBUTTON: RN1.8 (R7); also elsewhere on the board
-RD_PORT1A: J3.11, U11.10 (O5)
-RD_PORT1C: U11.9 (O6); also elsewhere on the board
-RD_PORT1E: U11.7 (O7); also elsewhere on the board
-RD_PORT10: J3.1, U11.15 (O0)
-RD_PORT12: J3.3, U11.14 (O1)
-RD_PORT14: J3.5, U11.13 (O2)
-RD_PORT16: J3.7, U11.12 (O3)
-RD_PORT18: J3.9, U11.11 (O4)
-WR_PORT1A: J3.12, U12.10 (O5)
-WR_PORT1C: U12.9 (O6); also elsewhere on the board
-WR_PORT1E: U12.7 (O7); also elsewhere on the board
-WR_PORT10: J3.2, U12.15 (O0)
-WR_PORT12: J3.4, U12.14 (O1)
-WR_PORT14: J3.6, U12.13 (O2)
-WR_PORT16: J3.8, U12.12 (O3)
-WR_PORT18: J3.10, U12.11 (O4)
BA1: U11.1 (A0), U12.1 (A0); also elsewhere on the board
BA2: U11.2 (A1), U12.2 (A1); also elsewhere on the board
BA3: U7.2 (A0), U11.3 (A2), U12.3 (A2); also elsewhere on the board
BA4: U7.3 (A1), U11.6 (E3), U12.6 (E3); also elsewhere on the board
BA5: U9.12 (R4); also elsewhere on the board
BA6: U9.9 (R3); also elsewhere on the board
BA7: U9.7 (R2); also elsewhere on the board
BA8: U9.5 (R1); also elsewhere on the board
BA9: U9.3 (R0); also elsewhere on the board
BAEN: U9.1 (G); also elsewhere on the board
BALE: U10.5; also elsewhere on the board
GND: C7.2, C8.2, C9.2, C10.2, C11.2, C12.2, J2.1, J2.3, J2.5, J2.7, J2.9, JP1.1 (A), U7.8 (GND), U8.8 (GND), U9.10 (GND), U9.13 (P5), U9.14 (R5), U9.15 (P6), U9.16 (R6), U9.17 (P7), U9.18 (R7), U10.7 (GND), U11.8 (GND), U12.8 (GND); also elsewhere on the board
unnamed: J2.2, RN1.2 (R1), U9.2 (P0)
unnamed: J2.4, RN1.3 (R2), U9.4 (P1)
unnamed: J2.6, RN1.4 (R3), U9.6 (P2)
unnamed: J2.8, RN1.5 (R4), U9.8 (P3)
unnamed: J2.10, RN1.6 (R5), U9.11 (P4)
unnamed: R1.2, RV1.1
unnamed: C13.1, U8.14 (Cext)
unnamed: C13.2, RV1.2, RV1.3, U8.15 (RCext)
unnamed: U8.1 (~A), U10.6
unnamed: U10.3, U10.4
PU1_10k_7: JP1.2 (B), RN1.7 (R6), U8.3 (~CLR)
PU1_10k_9: RN1.9 (R8)
VCC: C7.1, C8.1, C9.1, C10.1, C11.1, C12.1, R1.1, RN1.1 (common), U7.16 (VCC), U8.2 (B), U8.16 (VCC), U9.20 (VCC), U10.14 (VCC), U11.16 (VCC), U12.16 (VCC); also elsewhere on the board

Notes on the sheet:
used
PW Adjust PW = 0.7RC Nominal = 100-1000nS Trigger Delay = 55-80nS
A9 A8 A7 A6 A5
I/O Address A9-A5 11-000x-xxxx = 300-31F (1=open, 0=jumper)
WRITE Decoder
READ Decoder

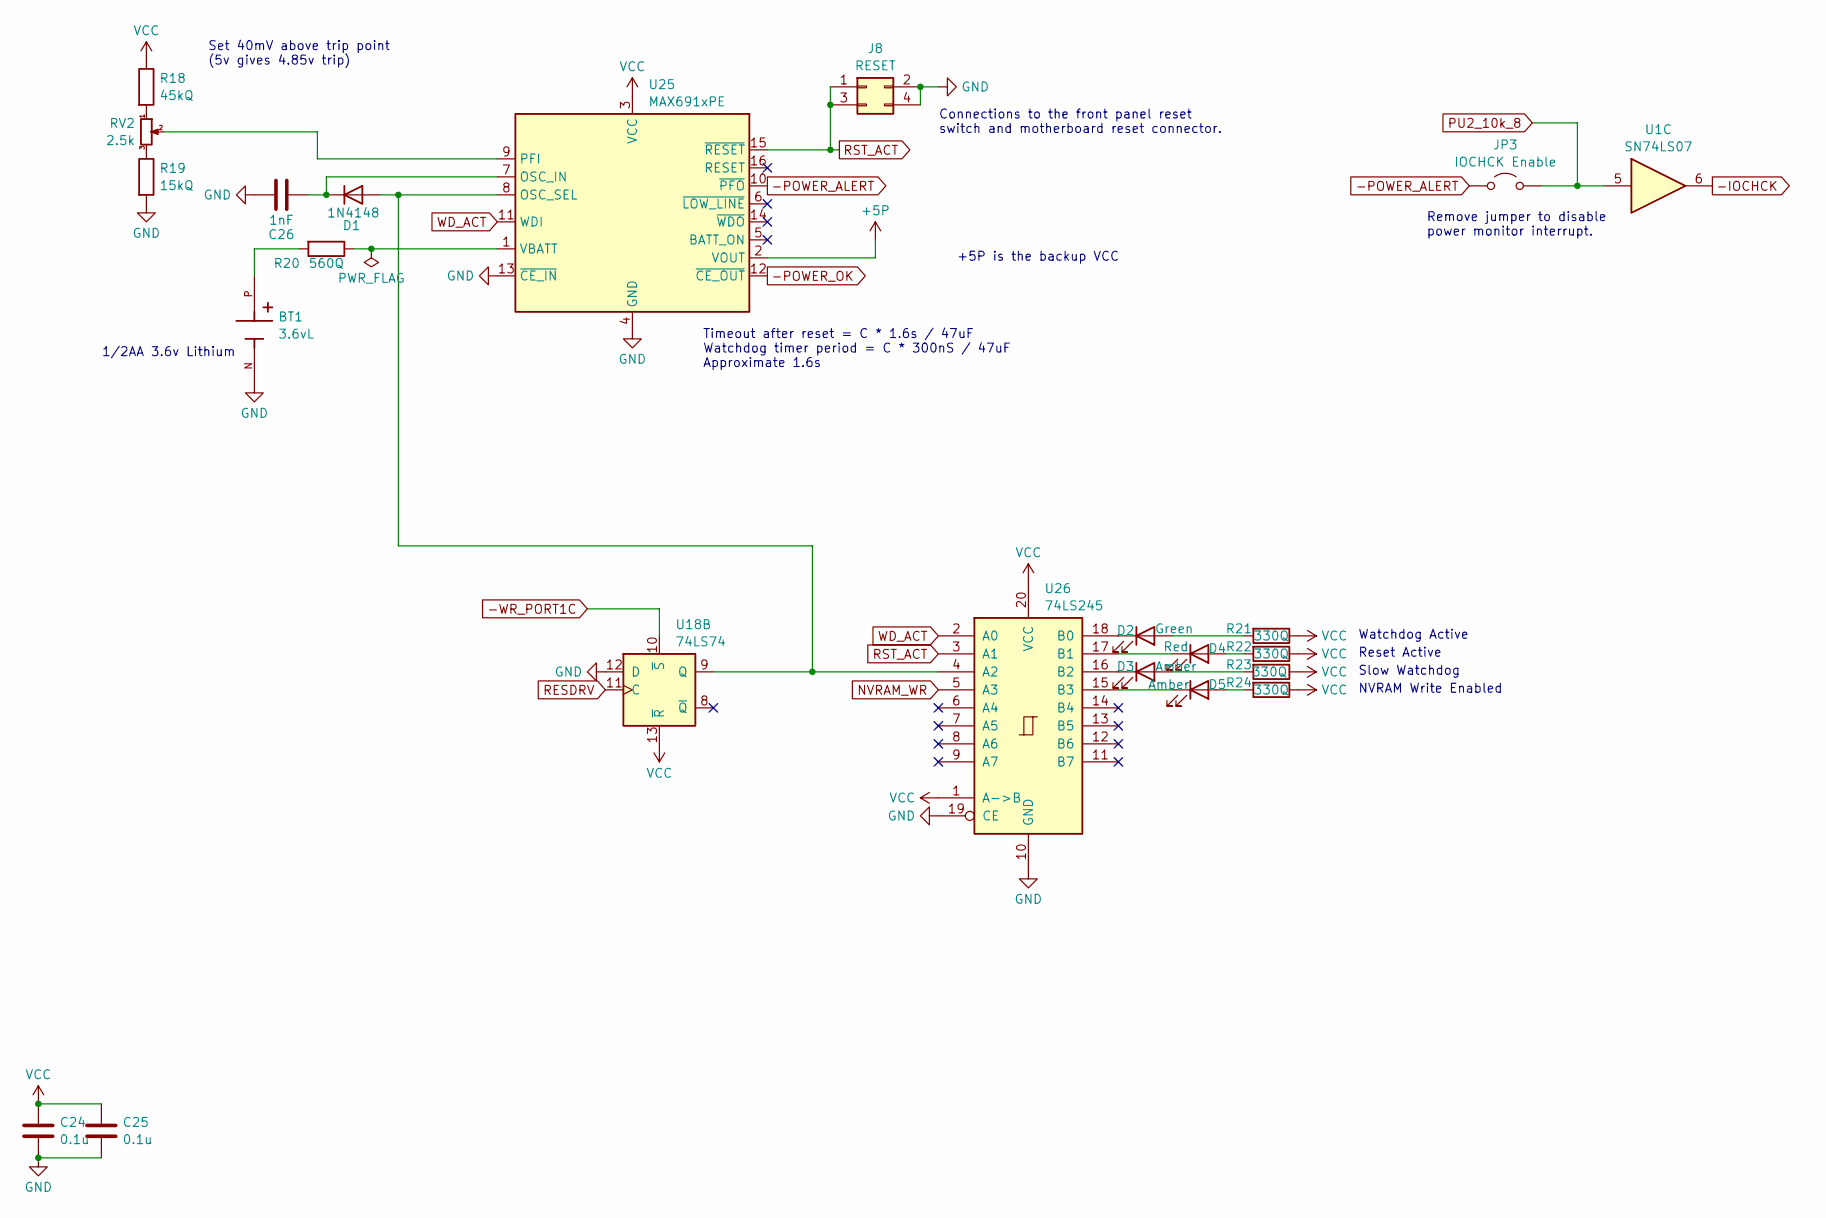
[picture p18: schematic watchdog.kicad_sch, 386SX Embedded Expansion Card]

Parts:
BT1: 3.6vL; BAT_2485; PARTREV B; DigiKey_Part_Number 36-2485-ND
C24, C25: 0.1u; C_Disc_D4.3mm_W1.9mm_P5.00mm
C26: 1nF; C_Disc_D3.0mm_W1.6mm_P2.50mm
D1: 1N4148; D_DO-35_SOD27_P7.62mm_Horizontal
D2: Green; LED_D3.0mm
D3, D5: Amber; LED_D3.0mm
D4: Red; LED_D3.0mm
J8: RESET; PinHeader_2x02_P2.54mm_Vertical
JP3: IOCHCK Enable; PinHeader_1x02_P2.54mm_Vertical
R18: 45kQ; R_Axial_DIN0207_L6.3mm_D2.5mm_P7.62mm_Horizontal
R19: 15kQ; R_Axial_DIN0207_L6.3mm_D2.5mm_P7.62mm_Horizontal
R20: 560Q; R_Axial_DIN0207_L6.3mm_D2.5mm_P7.62mm_Horizontal
R21, R22, R23, R24: 330Q; R_Axial_DIN0207_L6.3mm_D2.5mm_P7.62mm_Horizontal
RV2: 2.5k; Potentiometer_Bourns_3266W_Vertical
U1: SN74LS07; DIP-14_W7.62mm_Socket
U18: 74LS74; DIP-14_W7.62mm_Socket
U25: MAX691xPE; DIP-16_W7.62mm_Socket
U26: 74LS245; DIP-20_W7.62mm_Socket

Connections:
+5P: U25.2 (VOUT); also elsewhere on the board
-IOCHCK: U1.6; also elsewhere on the board
-POWER_ALERT: JP3.1 (A), U25.10 (~PFO); also elsewhere on the board
-POWER_OK: U25.12 (~CE_OUT); also elsewhere on the board
-WR_PORT1C: U18.10 (~S); also elsewhere on the board
GND: BT1.N, C24.2, C25.2, C26.2, J8.2, J8.4, R19.2, U18.12 (D), U25.4 (GND), U25.13 (~CE_IN), U26.10 (GND), U26.19 (CE); also elsewhere on the board
NVRAM_WR: U26.5 (A3); also elsewhere on the board
unnamed: BT1.P, R20.2
unnamed: D1.2 (A), U18.9 (Q), U25.8 (OSC_SEL), U26.4 (A2)
unnamed: C26.1, D1.1 (K), U25.7 (OSC_IN)
unnamed: D2.2 (A), R21.2
unnamed: D2.1 (K), U26.18 (B0)
unnamed: D3.2 (A), R23.2
unnamed: D3.1 (K), U26.16 (B2)
unnamed: D4.2 (A), R22.2
unnamed: D4.1 (K), U26.17 (B1)
unnamed: D5.2 (A), R24.2
unnamed: D5.1 (K), U26.15 (B3)
unnamed: R18.2, RV2.1
unnamed: R19.1, RV2.3
unnamed: RV2.2, U25.9 (PFI)
unnamed: R20.1, U25.1 (VBATT)
PU2_10k_8: JP3.2 (B), U1.5; also elsewhere on the board
RESDRV: U18.11 (C); also elsewhere on the board
RST_ACT: J8.1, J8.3, U25.15 (~RESET), U26.3 (A1)
VCC: C24.1, C25.1, R18.1, R21.1, R22.1, R23.1, R24.1, U18.13 (~R), U25.3 (VCC), U26.1 (A->B), U26.20 (VCC); also elsewhere on the board
WD_ACT: U25.11 (WDI), U26.2 (A0); also elsewhere on the board

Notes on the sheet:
Reset Active
Remove jumper to disable power monitor interrupt.
Slow Watchdog
Watchdog Active
+5P is the backup VCC
Set 40mV above trip point (5v gives 4.85v trip)
Timeout after reset = C * 1.6s / 47uF Watchdog timer period = C * 300nS / 47uF Approximate 1.6s
1/2AA 3.6v Lithium
Connections to the front panel reset switch and motherboard reset connector.
NVRAM Write Enabled

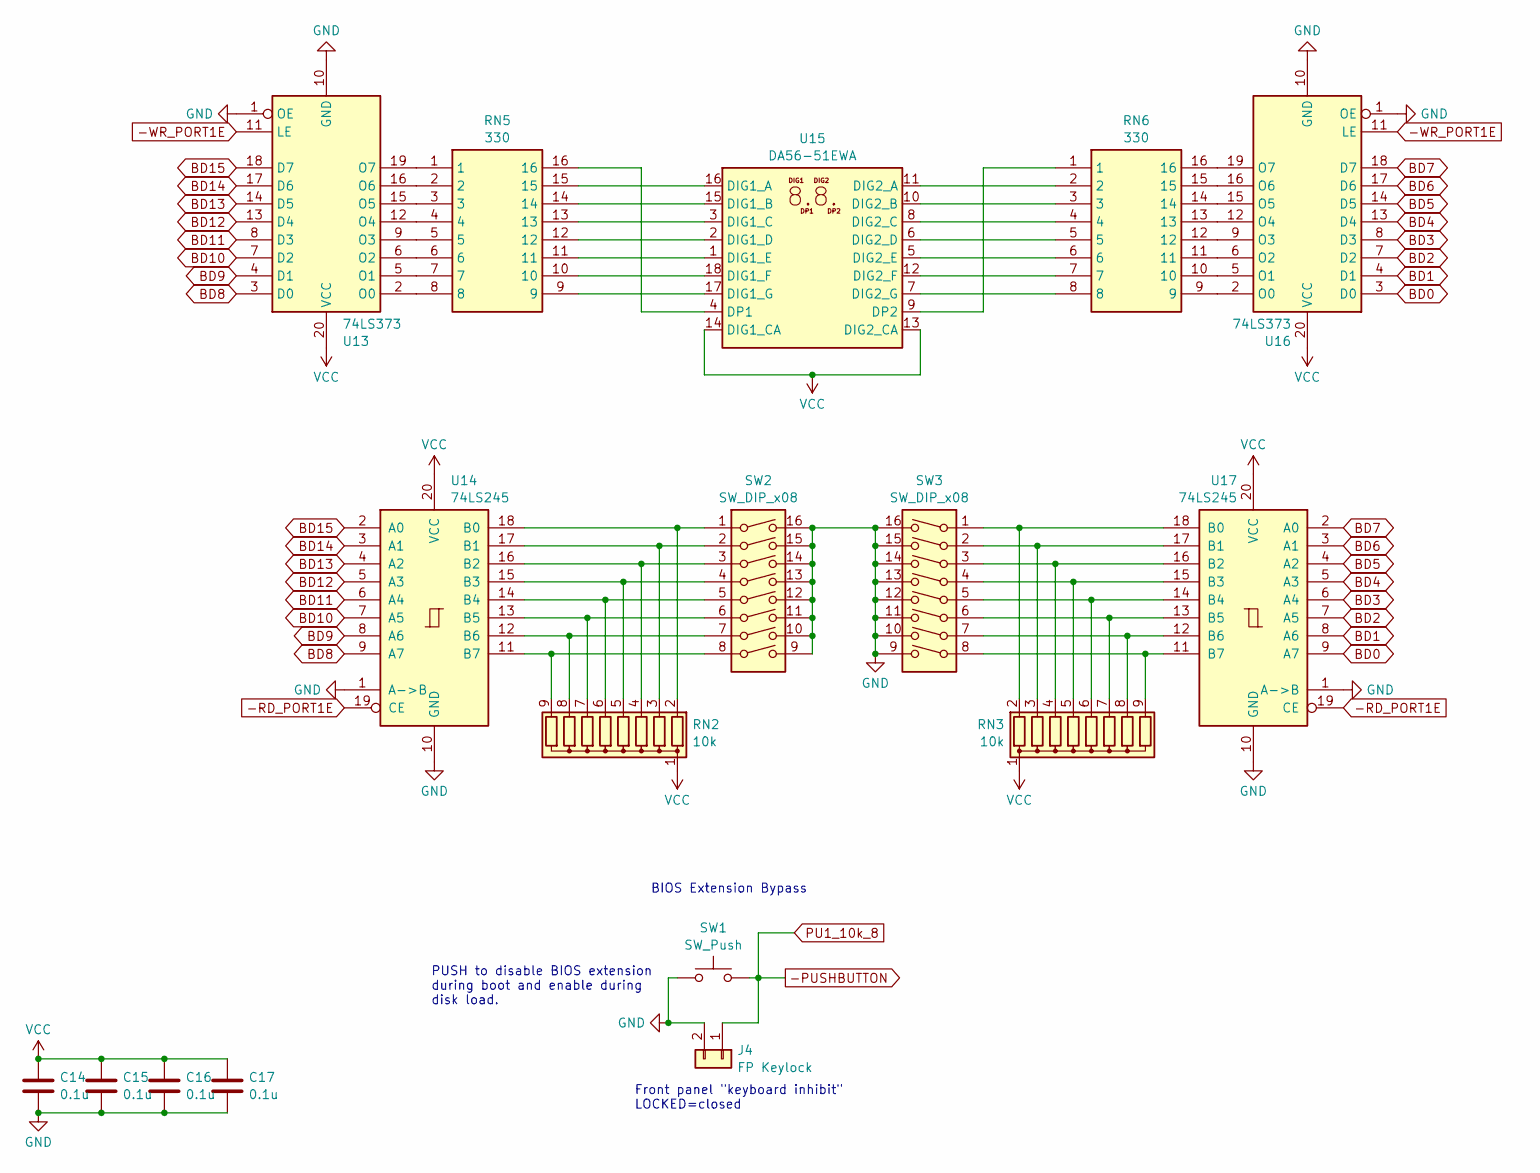
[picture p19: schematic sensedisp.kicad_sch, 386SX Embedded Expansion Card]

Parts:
C14, C15, C16, C17: 0.1u; C_Disc_D4.3mm_W1.9mm_P5.00mm
J4: FP Keylock; PinHeader_1x02_P2.54mm_Vertical
RN2, RN3: 10k; R_Array_SIP9
RN5, RN6: 330; DIP-16_W7.62mm_Socket; Mouser Part Number 652-4116R-1LF-330
SW1: SW_Push; SW_PUSH_6mm
SW2, SW3: SW_DIP_x08; DIP-16_W7.62mm_Socket
U13, U16: 74LS373; DIP-20_W7.62mm_Socket
U14, U17: 74LS245; DIP-20_W7.62mm_Socket
U15: DA56-51EWA; DA56-11SURKWA

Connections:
-PUSHBUTTON: J4.1, SW1.2; also elsewhere on the board
-RD_PORT1E: U14.19 (CE), U17.19 (CE); also elsewhere on the board
-WR_PORT1E: U13.11 (LE), U16.11 (LE); also elsewhere on the board
BD0: U16.3 (D0), U17.9 (A7); also elsewhere on the board
BD1: U16.4 (D1), U17.8 (A6); also elsewhere on the board
BD2: U16.7 (D2), U17.7 (A5); also elsewhere on the board
BD3: U16.8 (D3), U17.6 (A4); also elsewhere on the board
BD4: U16.13 (D4), U17.5 (A3); also elsewhere on the board
BD5: U16.14 (D5), U17.4 (A2); also elsewhere on the board
BD6: U16.17 (D6), U17.3 (A1); also elsewhere on the board
BD7: U16.18 (D7), U17.2 (A0); also elsewhere on the board
BD8: U13.3 (D0), U14.9 (A7); also elsewhere on the board
BD9: U13.4 (D1), U14.8 (A6); also elsewhere on the board
BD10: U13.7 (D2), U14.7 (A5); also elsewhere on the board
BD11: U13.8 (D3), U14.6 (A4); also elsewhere on the board
BD12: U13.13 (D4), U14.5 (A3); also elsewhere on the board
BD13: U13.14 (D5), U14.4 (A2); also elsewhere on the board
BD14: U13.17 (D6), U14.3 (A1); also elsewhere on the board
BD15: U13.18 (D7), U14.2 (A0); also elsewhere on the board
GND: C14.2, C15.2, C16.2, C17.2, J4.2, SW1.1, SW2.9, SW2.10, SW2.11, SW2.12, SW2.13, SW2.14, SW2.15, SW2.16, SW3.9, SW3.10, SW3.11, SW3.12, SW3.13, SW3.14, SW3.15, SW3.16, U13.1 (OE), U13.10 (GND), U14.1 (A->B), U14.10 (GND), U16.1 (OE), U16.10 (GND), U17.1 (A->B), U17.10 (GND); also elsewhere on the board
unnamed: RN2.2 (R1), SW2.1, U14.18 (B0)
unnamed: RN2.3 (R2), SW2.2, U14.17 (B1)
unnamed: RN2.4 (R3), SW2.3, U14.16 (B2)
unnamed: RN2.5 (R4), SW2.4, U14.15 (B3)
unnamed: RN2.6 (R5), SW2.5, U14.14 (B4)
unnamed: RN2.7 (R6), SW2.6, U14.13 (B5)
unnamed: RN2.8 (R7), SW2.7, U14.12 (B6)
unnamed: RN2.9 (R8), SW2.8, U14.11 (B7)
unnamed: RN3.2 (R1), SW3.1, U17.18 (B0)
unnamed: RN3.3 (R2), SW3.2, U17.17 (B1)
unnamed: RN3.4 (R3), SW3.3, U17.16 (B2)
unnamed: RN3.5 (R4), SW3.4, U17.15 (B3)
unnamed: RN3.6 (R5), SW3.5, U17.14 (B4)
unnamed: RN3.7 (R6), SW3.6, U17.13 (B5)
unnamed: RN3.8 (R7), SW3.7, U17.12 (B6)
unnamed: RN3.9 (R8), SW3.8, U17.11 (B7)
unnamed: RN5.8, U13.2 (O0)
unnamed: RN5.7, U13.5 (O1)
unnamed: RN5.6, U13.6 (O2)
unnamed: RN5.5, U13.9 (O3)
unnamed: RN5.4, U13.12 (O4)
unnamed: RN5.3, U13.15 (O5)
unnamed: RN5.2, U13.16 (O6)
unnamed: RN5.1, U13.19 (O7)
unnamed: RN5.15, U15.16 (DIG1_A)
unnamed: RN5.14, U15.15 (DIG1_B)
unnamed: RN5.13, U15.3 (DIG1_C)
unnamed: RN5.12, U15.2 (DIG1_D)
unnamed: RN5.11, U15.1 (DIG1_E)
unnamed: RN5.10, U15.18 (DIG1_F)
unnamed: RN5.9, U15.17 (DIG1_G)
unnamed: RN6.2, U15.11 (DIG2_A)
unnamed: RN6.3, U15.10 (DIG2_B)
unnamed: RN6.4, U15.8 (DIG2_C)
unnamed: RN6.5, U15.6 (DIG2_D)
unnamed: RN6.6, U15.5 (DIG2_E)
unnamed: RN6.7, U15.12 (DIG2_F)
unnamed: RN6.8, U15.7 (DIG2_G)
unnamed: RN5.16, U15.4 (DP1)
unnamed: RN6.1, U15.9 (DP2)
unnamed: RN6.9, U16.2 (O0)
unnamed: RN6.10, U16.5 (O1)
unnamed: RN6.11, U16.6 (O2)
unnamed: RN6.12, U16.9 (O3)
unnamed: RN6.13, U16.12 (O4)
unnamed: RN6.14, U16.15 (O5)
unnamed: RN6.15, U16.16 (O6)
unnamed: RN6.16, U16.19 (O7)
VCC: C14.1, C15.1, C16.1, C17.1, RN2.1 (common), RN3.1 (common), U13.20 (VCC), U14.20 (VCC), U15.13 (DIG2_CA), U15.14 (DIG1_CA), U16.20 (VCC), U17.20 (VCC); also elsewhere on the board

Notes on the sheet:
BIOS Extension Bypass
PUSH to disable BIOS extension during boot and enable during disk load.
Front panel "keyboard inhibit" LOCKED=closed

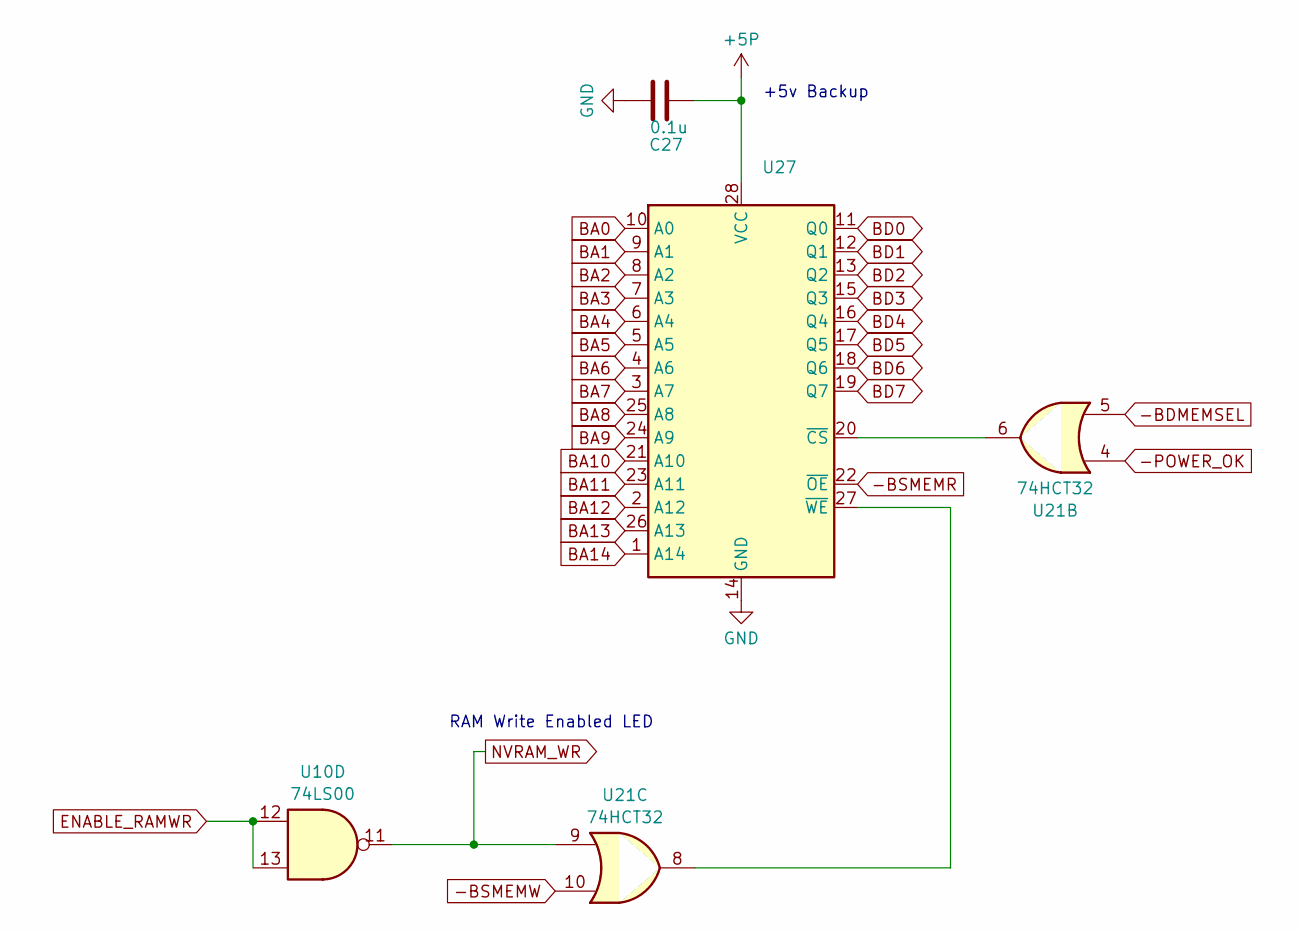
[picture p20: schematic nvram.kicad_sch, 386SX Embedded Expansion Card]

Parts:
C27: 0.1u; C_Disc_D4.3mm_W1.9mm_P5.00mm
U10: 74LS00; DIP-14_W7.62mm_Socket
U21: 74HCT32; DIP-14_W7.62mm_Socket
U27: HM62256BLP; DIP-28_W15.24mm_Socket

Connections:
+5P: C27.1, U27.28 (VCC); also elsewhere on the board
-BDMEMSEL: U21.5; also elsewhere on the board
-BSMEMR: U27.22 (~OE); also elsewhere on the board
-BSMEMW: U21.10; also elsewhere on the board
-POWER_OK: U21.4; also elsewhere on the board
BA0: U27.10 (A0); also elsewhere on the board
BA1: U27.9 (A1); also elsewhere on the board
BA2: U27.8 (A2); also elsewhere on the board
BA3: U27.7 (A3); also elsewhere on the board
BA4: U27.6 (A4); also elsewhere on the board
BA5: U27.5 (A5); also elsewhere on the board
BA6: U27.4 (A6); also elsewhere on the board
BA7: U27.3 (A7); also elsewhere on the board
BA8: U27.25 (A8); also elsewhere on the board
BA9: U27.24 (A9); also elsewhere on the board
BA10: U27.21 (A10); also elsewhere on the board
BA11: U27.23 (A11); also elsewhere on the board
BA12: U27.2 (A12); also elsewhere on the board
BA13: U27.26 (A13); also elsewhere on the board
BA14: U27.1 (A14); also elsewhere on the board
BD0: U27.11 (Q0); also elsewhere on the board
BD1: U27.12 (Q1); also elsewhere on the board
BD2: U27.13 (Q2); also elsewhere on the board
BD3: U27.15 (Q3); also elsewhere on the board
BD4: U27.16 (Q4); also elsewhere on the board
BD5: U27.17 (Q5); also elsewhere on the board
BD6: U27.18 (Q6); also elsewhere on the board
BD7: U27.19 (Q7); also elsewhere on the board
ENABLE_RAMWR: U10.12, U10.13; also elsewhere on the board
GND: C27.2, U27.14 (GND); also elsewhere on the board
NVRAM_WR: U10.11, U21.9; also elsewhere on the board
unnamed: U21.6, U27.20 (~CS)
unnamed: U21.8, U27.27 (~WE)

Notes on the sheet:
+5v Backup
RAM Write Enabled LED

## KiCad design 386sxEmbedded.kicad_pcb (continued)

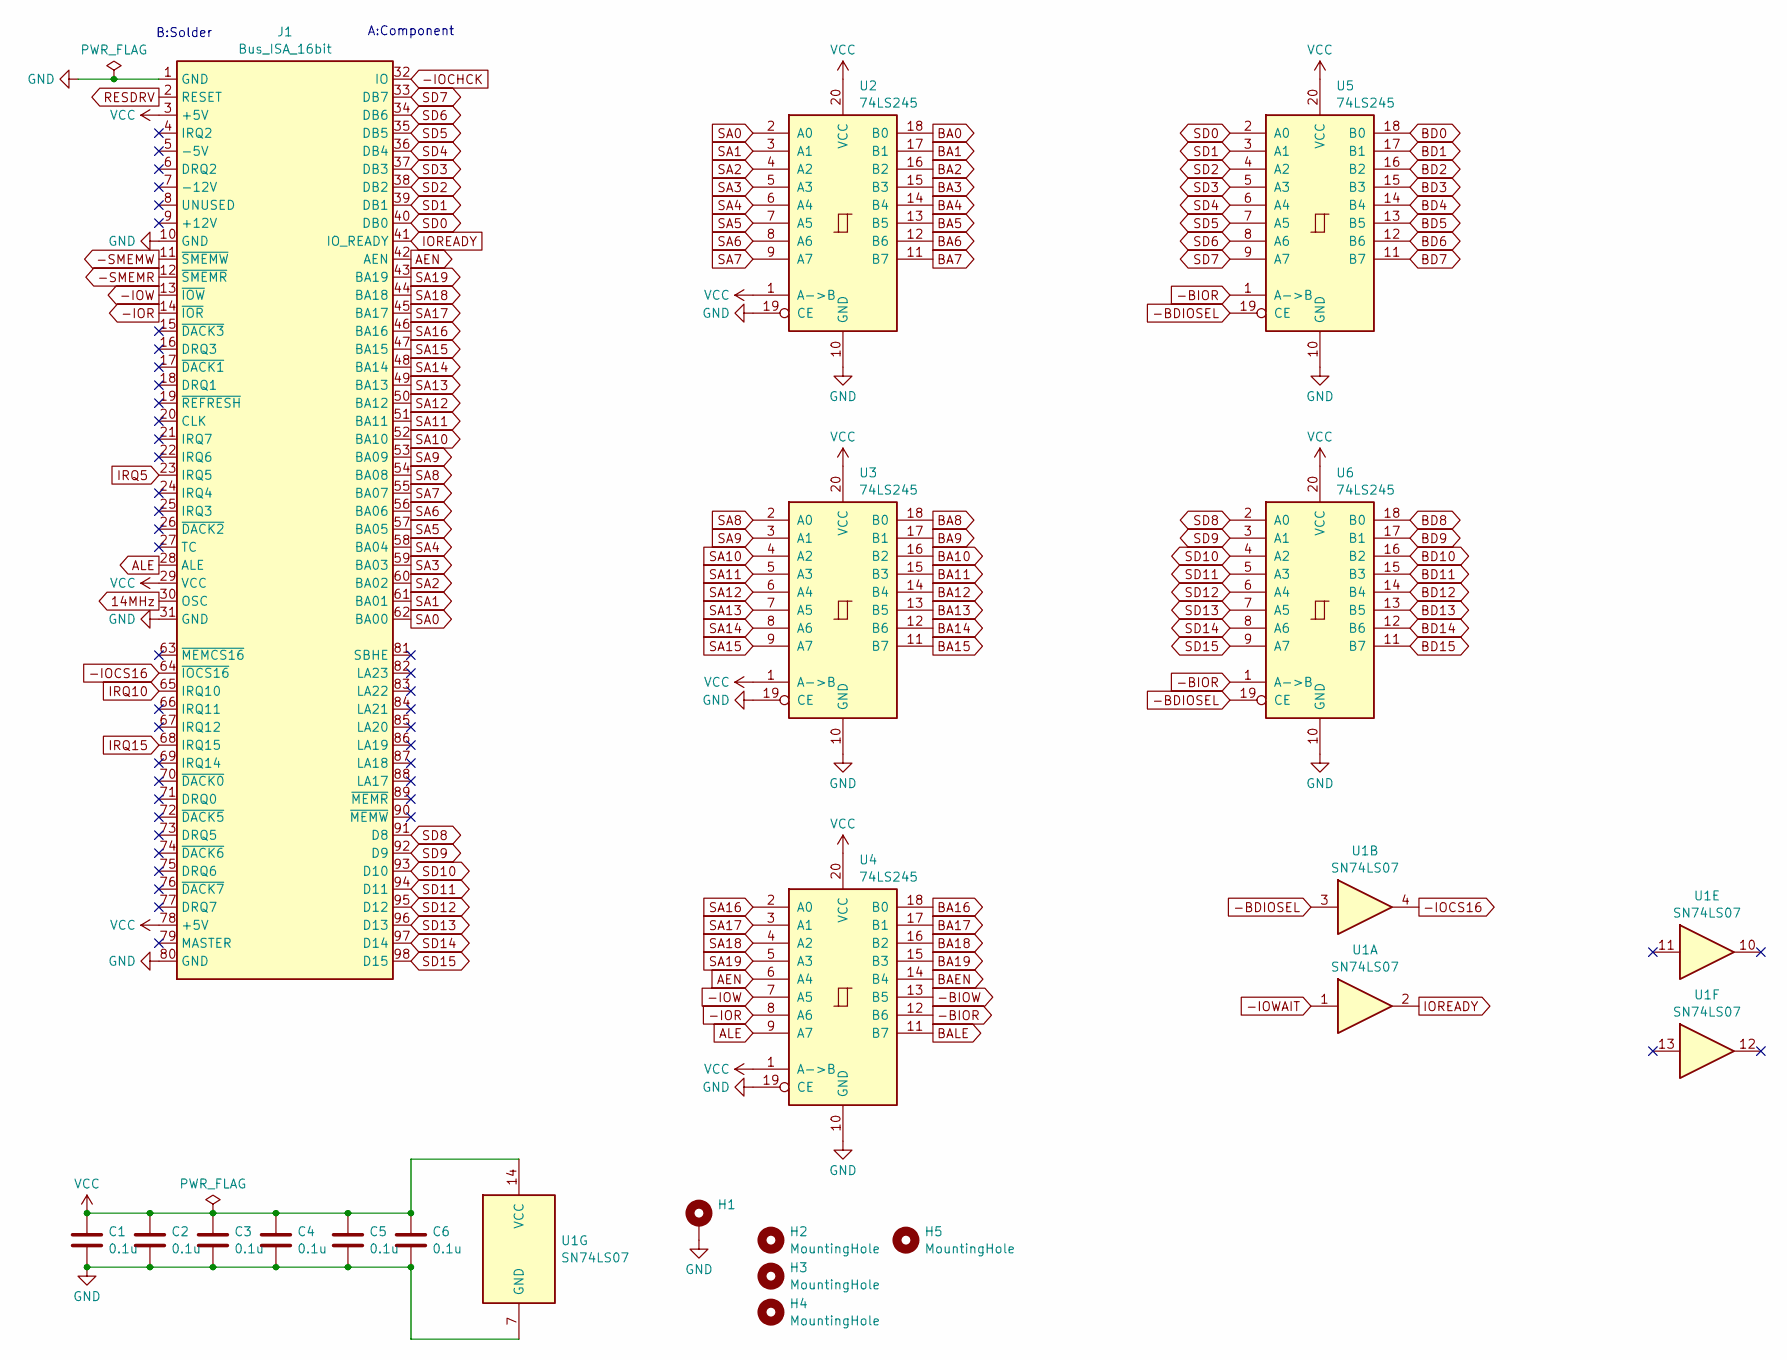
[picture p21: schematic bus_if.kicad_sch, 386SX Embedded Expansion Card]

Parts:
C1, C2, C3, C4, C5, C6: 0.1u; C_Disc_D4.3mm_W1.9mm_P5.00mm
H1: MountingHole_Pad; MountingHole_3.2mm_M3_Pad
H2, H3, H4, H5: MountingHole; MountingHole_3.2mm_M3
J1: Bus_ISA_16bit; BUS_AT
U1: SN74LS07; DIP-14_W7.62mm_Socket
U2, U3, U4, U5, U6: 74LS245; DIP-20_W7.62mm_Socket

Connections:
14MHz: J1.30 (OSC); also elsewhere on the board
-BDIOSEL: U1.3, U5.19 (CE), U6.19 (CE); also elsewhere on the board
-BIOR: U4.12 (B6), U5.1 (A->B), U6.1 (A->B); also elsewhere on the board
-BIOW: U4.13 (B5); also elsewhere on the board
-IOCHCK: J1.32 (IO); also elsewhere on the board
-IOCS16: J1.64 (~IOCS16), U1.4
-IOR: J1.14 (~IOR), U4.8 (A6)
-IOW: J1.13 (~IOW), U4.7 (A5)
-IOWAIT: U1.1; also elsewhere on the board
-SMEMR: J1.12 (~SMEMR); also elsewhere on the board
-SMEMW: J1.11 (~SMEMW); also elsewhere on the board
AEN: J1.42 (AEN), U4.6 (A4)
ALE: J1.28 (ALE), U4.9 (A7)
BA0: U2.18 (B0); also elsewhere on the board
BA1: U2.17 (B1); also elsewhere on the board
BA2: U2.16 (B2); also elsewhere on the board
BA3: U2.15 (B3); also elsewhere on the board
BA4: U2.14 (B4); also elsewhere on the board
BA5: U2.13 (B5); also elsewhere on the board
BA6: U2.12 (B6); also elsewhere on the board
BA7: U2.11 (B7); also elsewhere on the board
BA8: U3.18 (B0); also elsewhere on the board
BA9: U3.17 (B1); also elsewhere on the board
BA10: U3.16 (B2); also elsewhere on the board
BA11: U3.15 (B3); also elsewhere on the board
BA12: U3.14 (B4); also elsewhere on the board
BA13: U3.13 (B5); also elsewhere on the board
BA14: U3.12 (B6); also elsewhere on the board
BA15: U3.11 (B7); also elsewhere on the board
BA16: U4.18 (B0); also elsewhere on the board
BA17: U4.17 (B1); also elsewhere on the board
BA18: U4.16 (B2); also elsewhere on the board
BA19: U4.15 (B3); also elsewhere on the board
BAEN: U4.14 (B4); also elsewhere on the board
BALE: U4.11 (B7); also elsewhere on the board
BD0: U5.18 (B0); also elsewhere on the board
BD1: U5.17 (B1); also elsewhere on the board
BD2: U5.16 (B2); also elsewhere on the board
BD3: U5.15 (B3); also elsewhere on the board
BD4: U5.14 (B4); also elsewhere on the board
BD5: U5.13 (B5); also elsewhere on the board
BD6: U5.12 (B6); also elsewhere on the board
BD7: U5.11 (B7); also elsewhere on the board
BD8: U6.18 (B0); also elsewhere on the board
BD9: U6.17 (B1); also elsewhere on the board
BD10: U6.16 (B2); also elsewhere on the board
BD11: U6.15 (B3); also elsewhere on the board
BD12: U6.14 (B4); also elsewhere on the board
BD13: U6.13 (B5); also elsewhere on the board
BD14: U6.12 (B6); also elsewhere on the board
BD15: U6.11 (B7); also elsewhere on the board
GND: C1.2, C2.2, C3.2, C4.2, C5.2, C6.2, H1.1, J1.1 (GND), J1.10 (GND), J1.31 (GND), J1.80 (GND), U1.7 (GND), U2.10 (GND), U2.19 (CE), U3.10 (GND), U3.19 (CE), U4.10 (GND), U4.19 (CE), U5.10 (GND), U6.10 (GND); also elsewhere on the board
IOREADY: J1.41 (IO_READY), U1.2
IRQ5: J1.23 (IRQ5); also elsewhere on the board
IRQ10: J1.65 (IRQ10); also elsewhere on the board
IRQ15: J1.68 (IRQ15); also elsewhere on the board
RESDRV: J1.2 (RESET); also elsewhere on the board
SA0: J1.62 (BA00), U2.2 (A0)
SA1: J1.61 (BA01), U2.3 (A1)
SA2: J1.60 (BA02), U2.4 (A2)
SA3: J1.59 (BA03), U2.5 (A3)
SA4: J1.58 (BA04), U2.6 (A4)
SA5: J1.57 (BA05), U2.7 (A5)
SA6: J1.56 (BA06), U2.8 (A6)
SA7: J1.55 (BA07), U2.9 (A7)
SA8: J1.54 (BA08), U3.2 (A0)
SA9: J1.53 (BA09), U3.3 (A1)
SA10: J1.52 (BA10), U3.4 (A2)
SA11: J1.51 (BA11), U3.5 (A3)
SA12: J1.50 (BA12), U3.6 (A4)
SA13: J1.49 (BA13), U3.7 (A5)
SA14: J1.48 (BA14), U3.8 (A6)
SA15: J1.47 (BA15), U3.9 (A7)
SA16: J1.46 (BA16), U4.2 (A0)
SA17: J1.45 (BA17), U4.3 (A1)
SA18: J1.44 (BA18), U4.4 (A2)
SA19: J1.43 (BA19), U4.5 (A3)
SD0: J1.40 (DB0), U5.2 (A0); also elsewhere on the board
SD1: J1.39 (DB1), U5.3 (A1); also elsewhere on the board
SD2: J1.38 (DB2), U5.4 (A2); also elsewhere on the board
SD3: J1.37 (DB3), U5.5 (A3); also elsewhere on the board
SD4: J1.36 (DB4), U5.6 (A4); also elsewhere on the board
SD5: J1.35 (DB5), U5.7 (A5); also elsewhere on the board
SD6: J1.34 (DB6), U5.8 (A6); also elsewhere on the board
SD7: J1.33 (DB7), U5.9 (A7); also elsewhere on the board
SD8: J1.91 (D8), U6.2 (A0)
SD9: J1.92 (D9), U6.3 (A1)
SD10: J1.93 (D10), U6.4 (A2)
SD11: J1.94 (D11), U6.5 (A3)
SD12: J1.95 (D12), U6.6 (A4)
SD13: J1.96 (D13), U6.7 (A5)
SD14: J1.97 (D14), U6.8 (A6)
SD15: J1.98 (D15), U6.9 (A7)
VCC: C1.1, C2.1, C3.1, C4.1, C5.1, C6.1, J1.3 (+5V), J1.29 (VCC), J1.78 (+5V), U1.14 (VCC), U2.1 (A->B), U2.20 (VCC), U3.1 (A->B), U3.20 (VCC), U4.1 (A->B), U4.20 (VCC), U5.20 (VCC), U6.20 (VCC); also elsewhere on the board

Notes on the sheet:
B:Solder
A:Component

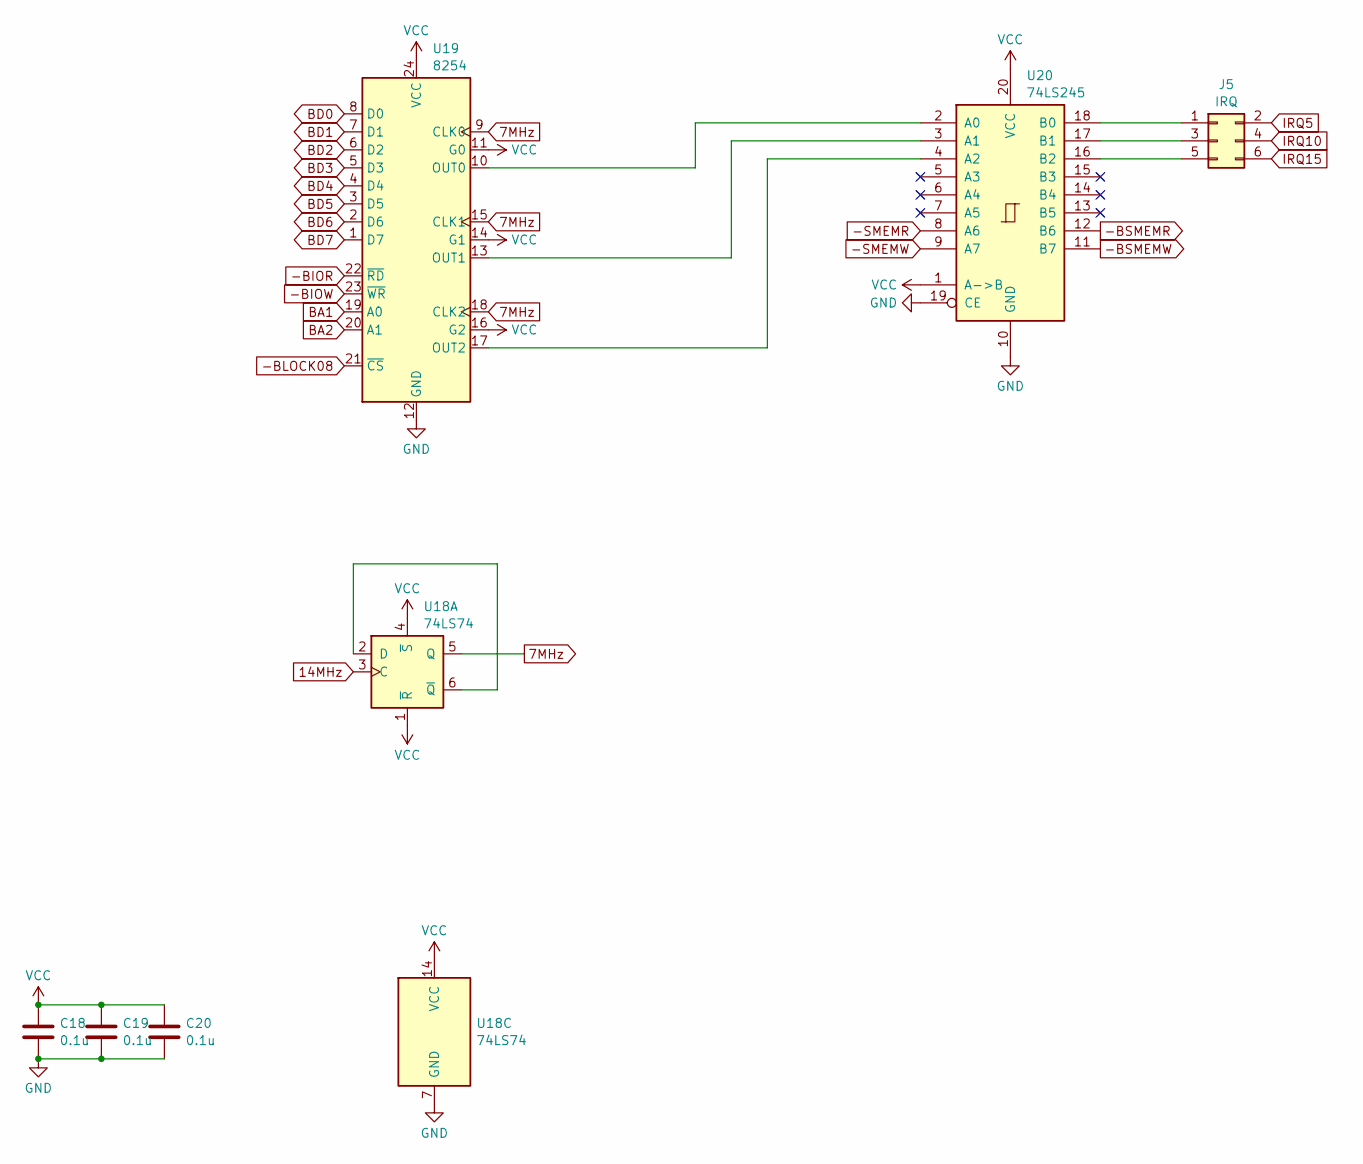
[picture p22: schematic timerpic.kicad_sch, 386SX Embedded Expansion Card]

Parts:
C18, C19, C20: 0.1u; C_Disc_D4.3mm_W1.9mm_P5.00mm
J5: IRQ; PinHeader_2x03_P2.54mm_Vertical
U18: 74LS74; DIP-14_W7.62mm_Socket
U19: 8254; DIP-24_W15.24mm
U20: 74LS245; DIP-20_W7.62mm_Socket

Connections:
7MHz: U18.5 (Q), U19.9 (CLK0), U19.15 (CLK1), U19.18 (CLK2)
14MHz: U18.3 (C); also elsewhere on the board
-BIOR: U19.22 (~RD); also elsewhere on the board
-BIOW: U19.23 (~WR); also elsewhere on the board
-BLOCK08: U19.21 (~CS); also elsewhere on the board
-BSMEMR: U20.12 (B6); also elsewhere on the board
-BSMEMW: U20.11 (B7); also elsewhere on the board
-SMEMR: U20.8 (A6); also elsewhere on the board
-SMEMW: U20.9 (A7); also elsewhere on the board
BA1: U19.19 (A0); also elsewhere on the board
BA2: U19.20 (A1); also elsewhere on the board
BD0: U19.8 (D0); also elsewhere on the board
BD1: U19.7 (D1); also elsewhere on the board
BD2: U19.6 (D2); also elsewhere on the board
BD3: U19.5 (D3); also elsewhere on the board
BD4: U19.4 (D4); also elsewhere on the board
BD5: U19.3 (D5); also elsewhere on the board
BD6: U19.2 (D6); also elsewhere on the board
BD7: U19.1 (D7); also elsewhere on the board
GND: C18.2, C19.2, C20.2, U18.7 (GND), U19.12 (GND), U20.10 (GND), U20.19 (CE); also elsewhere on the board
IRQ5: J5.2; also elsewhere on the board
IRQ10: J5.4; also elsewhere on the board
IRQ15: J5.6; also elsewhere on the board
unnamed: J5.1, U20.18 (B0)
unnamed: J5.3, U20.17 (B1)
unnamed: J5.5, U20.16 (B2)
unnamed: U18.2 (D), U18.6 (~Q)
unnamed: U19.10 (OUT0), U20.2 (A0)
unnamed: U19.13 (OUT1), U20.3 (A1)
unnamed: U19.17 (OUT2), U20.4 (A2)
VCC: C18.1, C19.1, C20.1, U18.1 (~R), U18.4 (~S), U18.14 (VCC), U19.11 (G0), U19.14 (G1), U19.16 (G2), U19.24 (VCC), U20.1 (A->B), U20.20 (VCC); also elsewhere on the board

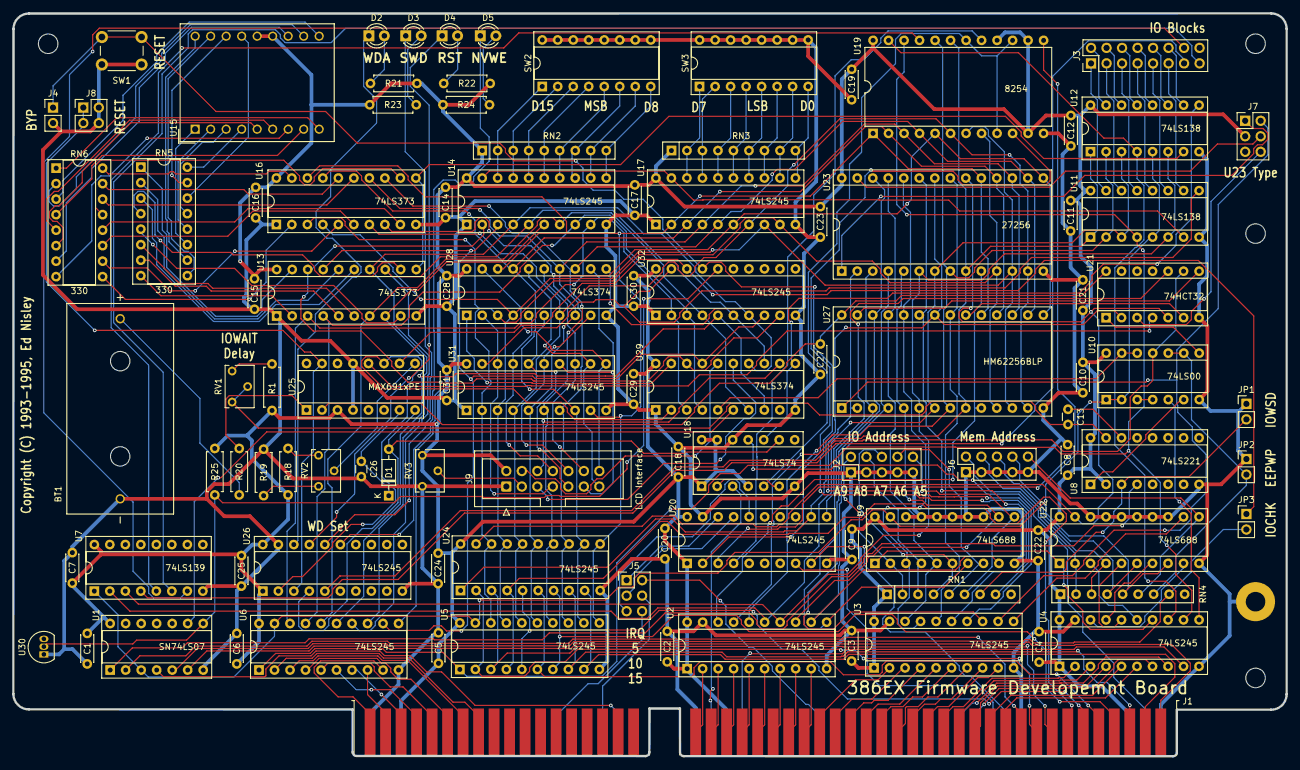
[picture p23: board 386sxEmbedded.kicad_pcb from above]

Board: 2 copper layers, 208.6 x 121.7 mm, 107 parts (0 on the bottom side), 235 nets.

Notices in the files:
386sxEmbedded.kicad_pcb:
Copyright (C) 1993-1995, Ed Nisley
